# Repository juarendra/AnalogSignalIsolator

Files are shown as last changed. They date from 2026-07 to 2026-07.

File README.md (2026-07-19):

# Analog Signal Isolator

> Isolator sinyal analog 0–5 V untuk menghubungkan sensor ke ESP32, Arduino, MCU, atau PLC tanpa menyatukan ground kedua sisi.

> [!NOTE]
> Panduan pembeli pada halaman ini berlaku untuk PCB yang silkscreen-nya bertuliskan **`AIN`**, **`AOUT`**, `MCU SIDE`, `SENSOR SIDE`, dan `FIT ONE ONLY`.

> [!TIP]
> Produk dikirim sebagai **satu PCB yang sudah dirakit**. Mode bawaan untuk ESP32, yaitu `M2.4V1`, sudah terpasang. Paket tidak mencakup sensor, kabel, catu daya, maupun board ESP32.

<p align="center">
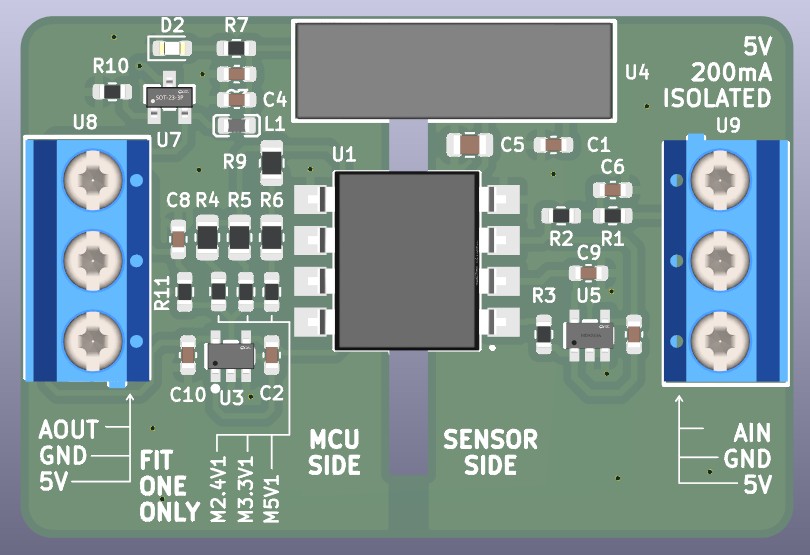
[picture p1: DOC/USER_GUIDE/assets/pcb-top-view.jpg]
PCB Analog Signal Isolator — tampak atas
  
</p>

<p align="center">
  <a href="DOC/USER_GUIDE/start-here.html"><strong>Mulai pemasangan PCB AIN/AOUT &rarr;</strong></a>
  &nbsp;·&nbsp;
  <a href="DOC/USER_GUIDE/assets/pinout-pcb-infographic.png"><strong>Unduh gambar pinout &rarr;</strong></a>
</p>

## Produk ini untuk apa?

Analog Signal Isolator adalah **jembatan aman untuk sinyal analog 0–5 V**. Modul ini menerima tegangan dari sensor di satu sisi, lalu mengirimkan kembali nilai yang sama secara analog ke ADC mikrokontroler/PLC di sisi lain—tanpa hubungan listrik langsung antara kedua ground.

Masalah yang diselesaikan modul ini adalah *ground loop*, noise, dan gangguan ketika sensor berada di mesin/panel yang berbeda dengan ESP32, Arduino, PLC, data logger, atau komputer yang terhubung USB. Sensor tetap memperoleh catu 5 V dari sisi terisolasi, sedangkan MCU membaca sinyal melalui `AOUT`.

```text
Sensor 0–5 V       Isolator analog optik              Mikrokontroler / PLC

AIN ─────────────▶ [ SENSOR SIDE  ║  MCU SIDE ] ─────────────▶ AOUT → ADC
GND sensor         ground terpisah / tidak tersambung          GND MCU
```

**Intinya:** jika sensor menunjukkan 2,50 V pada `AIN`, modul meneruskan nilai proporsional pada `AOUT` sesuai mode yang dipilih. Perangkat lunak kemudian mengubah pembacaan ADC tersebut kembali menjadi nilai sensor melalui kalibrasi dua titik.

## Contoh aplikasi

| Aplikasi | Cara modul digunakan | Manfaat |
| --- | --- | --- |
| **Data logger ESP32** | Sensor tekanan, level, atau posisi 0–5 V dipasang di sisi sensor; `AOUT` dibaca ESP32 pada sisi MCU. | Mengurangi noise dan risiko gangguan ground saat ESP32 memakai USB/Wi-Fi. |
| **Monitoring panel mesin** | Sensor analog pada panel mesin dihubungkan ke `AIN`; sistem monitoring terpisah membaca `AOUT`. | Ground sistem monitoring tidak perlu disatukan dengan ground panel. |
| **Input analog PLC** | Sinyal sensor 0–5 V diteruskan ke input analog PLC melalui sisi MCU. | Membantu pemisahan domain sensor dan kontrol. |
| **Gateway IoT retrofit** | Tambahkan ESP32/Arduino untuk membaca keluaran sensor pada alat lama tanpa mengubah wiring sensor utama. | Integrasi monitoring jarak jauh lebih aman dan rapi. |

> Modul ini bekerja untuk **tegangan analog DC 0–5 V yang sudah dikondisikan**. Untuk sensor 4–20 mA, RTD, thermocouple, AC, atau tegangan PLN, gunakan rangkaian pengondisi sinyal yang tepat terlebih dahulu.

## Kenapa menggunakan modul ini?

- **Isolasi galvanik** antara sisi sensor dan sisi MCU/PLC untuk membantu mengurangi *ground loop* dan gangguan.
- **Input sensor 0–5 V DC** dengan keluaran analog terisolasi `AOUT`.
- **Catu sensor 5 V terisolasi** tersedia langsung pada konektor sisi sensor, hingga **150 mA kontinu** untuk beban sensor.
- **Mode ESP32 2,4 V** sudah dipilih dari pabrik (`M2.4V1`); pilihan lain hanya untuk perubahan konfigurasi terkontrol.
- **Siap untuk dokumentasi dan produksi:** proyek KiCad, Gerber, BOM, skematik, serta prosedur pengujian tersedia di repositori.

## Gambaran koneksi

| MCU SIDE | SENSOR SIDE |
| --- | --- |
| `5V` — catu masuk modul | `5V` — catu keluar terisolasi untuk sensor (maks. 150 mA kontinu) |
| `GND` — ground MCU/PLC | `GND` — ground sensor terisolasi |
| `AOUT` — ke input ADC | `AIN` — dari output sensor 0–5 V |

> [!CAUTION]
> **Jangan hubungkan ground MCU ke ground sensor.** Kedua sisi harus tetap terpisah agar isolasi bekerja.

## Mulai cepat

1. Buka [Mulai di Sini — PCB AIN/AOUT](DOC/USER_GUIDE/start-here.html).
2. Pastikan `M2.4V1` masih terpasang sebagai mode bawaan ESP32. Jangan mengubah jumper mode kecuali Anda memang mengganti jenis host.
3. Hubungkan sensor 0–5 V ke `AIN` dan `GND` pada **SENSOR SIDE**.
4. Hubungkan ADC ke `AOUT`, catu +5 V ke `5V`, dan ground host ke `GND` pada **MCU SIDE**.
5. Nyalakan catu 5 V yang teratur dan memiliki pembatas arus, kemudian kalibrasikan pembacaan 0 V dan 5 V.

## Batas catu untuk sensor

Konektor `5V` pada **SENSOR SIDE** adalah keluaran dari DC/DC isolasi, bukan catu 5 V berdaya besar.

- Gunakan beban sensor total **maksimum 150 mA secara kontinu** (gabungan arus sensor dan aksesori yang mengambil daya dari konektor ini).
- Rating modul DC/DC yang dipasang adalah 5 V / 200 mA, tetapi sebagian arus dipakai oleh rangkaian isolator dan perlu margin untuk suhu serta lonjakan awal. Karena itu **200 mA bukan batas beban sensor eksternal**.
- Bila sensor memiliki arus *inrush*, relay, pemanas, atau motor, gunakan catu sensor terisolasi eksternal yang sesuai. Jangan mengambil daya beban tersebut dari PCB ini.

## Proteksi sistem yang direkomendasikan

Diagram proteksi catu eksternal

PCB ini tidak memasang TVS atau PPTC. Untuk instalasi panel/mesin, pasang proteksi **di luar PCB** pada sisi yang tepat:

1. Gunakan catu **5 V DC teratur**; jangan hubungkan sumber dengan tegangan lebih dari 5 V ke `5V` pada MCU SIDE.
2. Pada kabel `+5V` menuju MCU SIDE, pasang **sekering atau PPTC**. Tentukan nilai *hold/trip* dari arus sistem dan uji arus awal; sebagai titik awal desain, rentang 250–500 mA lazim untuk jalur modul ini, bukan nilai yang otomatis cocok untuk semua sistem.
3. Pasang **TVS unidirectional dengan tegangan kerja 5 V** antara `+5V` dan `GND` **setelah** sekering/PPTC. Pilih energi impuls dan tegangan jepit berdasarkan lingkungan serta kemampuan catu; TVS bukan pengganti sekering.
4. Untuk kabel sensor panjang atau berada di lingkungan berisiko gangguan, TVS 5 V tambahan boleh dipasang dekat konektor **SENSOR SIDE**, dari `5V` ke `GND` sensor saja. Gunakan pelindung sinyal yang dirancang untuk jenis sensor pada jalur `AIN`; jangan memasang komponen sembarang yang mengubah akurasi sinyal.
5. Bila ada shield kabel, terminasi ke chassis/earth di titik masuk panel sesuai praktik sistem. Jangan memakai shield atau perangkat ukur untuk menyatukan `GND` sensor dan `GND` MCU.

> [!WARNING]
> Jangan memasang TVS, jumper, kabel, atau ground melintasi celah/penghalang isolasi. Untuk petir atau surge energi tinggi, gunakan SPD pada pintu masuk sistem dan catu yang sesuai. PCB ini bukan penangkal petir maupun perangkat bersertifikasi keselamatan.

## Dokumentasi

| Dokumen | Kegunaan |
| --- | --- |
| [Mulai di Sini — PCB AIN/AOUT](DOC/USER_GUIDE/start-here.html) | Panduan utama pembeli: jumper, wiring ESP32, uji pertama, dan troubleshooting. |
| [Pinout visual](DOC/USER_GUIDE/pinout-pcb.html) | Cara pemasangan dari foto PCB atas/bawah; buka di browser. |
| [Gambar pinout siap dibagikan](DOC/USER_GUIDE/assets/pinout-pcb-infographic.png) | Infografik untuk pembeli, marketplace, atau teknisi lapangan. |
| [Panduan pengguna](DOC/USER_GUIDE/panduan-visual.html) | Penjelasan kerja, mode, wiring, kalibrasi, dan troubleshooting. |
| [Indeks dokumen teknis](DOC/README.md) | Skematik, BOM, aturan PCB, dan prosedur pengujian. |

## Struktur proyek

| Folder | Isi |
| --- | --- |
| `DOC/USER_GUIDE/` | Panduan pembeli, pinout, gambar produk, dan aset visual. |
| `DOC/` | Skematik, BOM, pengujian, serta referensi teknis Rev B2. |
| `PCB/AnalogIsolator/AnalogIsolator/` | Proyek KiCad, library lokal, Gerber, dan drill file produksi. |

> Rev B2 tidak memasang TVS dan sekering resettable (PPTC) pada papan. Untuk pemasangan yang andal, gunakan catu host 5 V yang teratur, dibatasi arus, dan perlindungan surge pada level sistem bila diperlukan.

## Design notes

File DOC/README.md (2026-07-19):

# Dokumentasi Analog Signal Isolator

Folder ini dipisahkan berdasarkan tujuan agar file yang dibutuhkan pengguna, teknisi, dan produksi tidak tercampur.

| Lokasi | Isi |
| --- | --- |
| [`USER_GUIDE/`](USER_GUIDE/) | Panduan pembeli/pengguna, halaman visual, foto PCB, dan pinout. |
| `00`–`05` | Diagram blok, skematik, pemilihan mode, dan pengkabelan Rev B2. |
| `06_BOM_and_Calculations_RevB2_LCSC.xlsx` | BOM, nilai komponen, dan perhitungan desain. |
| [`09_BOM_Latest_Schematic_LCSC_Mouser.xlsx`](09_BOM_Latest_Schematic_LCSC_Mouser.xlsx) | BOM baru hasil cocokkan dengan skematik saat ini; mencantumkan sumber LCSC dan Mouser serta item yang perlu disetujui. Lihat [catatan validasi](09_BOM_Latest_Schematic_LCSC_Mouser.md). |
| `07`–`08` | Aturan layout PCB serta pengujian/kalibrasi. |

Mulai dari [`USER_GUIDE/start-here.html`](USER_GUIDE/start-here.html) untuk pemasangan PCB fisik yang bertuliskan `AIN/AOUT`. Versi Markdown: [`USER_GUIDE/START_HERE_ID.md`](USER_GUIDE/START_HERE_ID.md). Referensi Rev B2 lama tetap tersedia untuk teknisi.

## Catatan revisi

Foto PCB yang tersedia memperlihatkan pemilih mode berupa jumper solder `M2.4V1`, `M3.3V1`, dan `M5V1`. Dokumen teknik Rev B2 yang lebih lama menyebut `SW1` serta target 2,4/3,0/4,5 V. Selalu ikuti silkscreen dan BOM pada PCB yang benar-benar diterima, lalu lakukan kalibrasi dua titik.

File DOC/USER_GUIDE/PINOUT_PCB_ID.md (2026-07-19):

# Pinout PCB — Analog Signal Isolator

Dokumen ini adalah rujukan pemasangan untuk PCB yang ditunjukkan pada foto di bawah. Gunakan tulisan silkscreen pada PCB sebagai rujukan terakhir apabila orientasi foto atau terminal berbeda.

Untuk pemasangan pertama PCB bertuliskan `AIN/AOUT`, mulai dari [Mulai di Sini](START_HERE_ID.md). Dokumen ini adalah referensi pinout pelengkap.

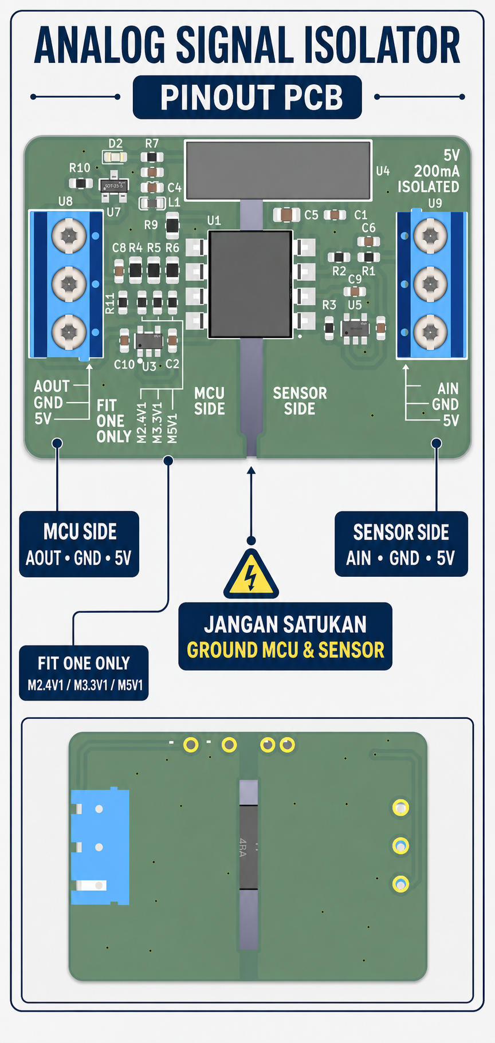
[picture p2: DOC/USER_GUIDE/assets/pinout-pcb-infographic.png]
Infografik pinout PCB


PCB tampak atas

## Konektor

| Sisi PCB | Label silkscreen | Fungsi | Sambungkan ke |
| --- | --- | --- | --- |
| **MCU SIDE** | `AOUT` | Keluaran analog terisolasi | Pin ADC / input analog pada mikrokontroler atau PLC |
| **MCU SIDE** | `GND` | Ground host | Ground mikrokontroler/PLC |
| **MCU SIDE** | `5V` | Catu masuk modul | +5 V DC yang teratur dan dibatasi arus |
| **SENSOR SIDE** | `AIN` | Masukan sinyal analog | Output sensor 0–5 V DC |
| **SENSOR SIDE** | `GND` | Ground sensor terisolasi | Ground sensor saja |
| **SENSOR SIDE** | `5V` | Catu keluar terisolasi untuk sensor | VCC sensor 5 V, maks. 150 mA kontinu |

> [!CAUTION]
> Jangan menghubungkan `GND` pada sisi MCU ke `GND` pada sisi SENSOR. Sambungan tersebut menghilangkan isolasi galvanik.

## Urutan sambungan yang aman

1. Matikan catu daya.
2. Hubungkan `5V`, `GND`, dan `AOUT` pada **MCU SIDE**.
3. Hubungkan `5V`, `GND`, dan `AIN` pada **SENSOR SIDE**.
4. Periksa kembali bahwa output sensor adalah 0–5 V DC terhadap ground sensor.
5. Pastikan tidak ada kabel atau perangkat lain yang menyatukan kedua ground.
6. Pastikan mode bawaan `M2.4V1` masih terpasang untuk ESP32, kemudian nyalakan catu +5 V host.

## Pemilih mode pada PCB ini

Area pemilih mode pada PCB

PCB pada foto menggunakan tiga footprint jumper solder/0 Ω bertuliskan `M2.4V1`, `M3.3V1`, dan `M5V1` dengan instruksi **FIT ONE ONLY**. Produk standar dikirim sebagai PCB rakitan dengan `M2.4V1` sudah terpasang untuk ESP32.

- Biarkan `M2.4V1` terpasang untuk ESP32.
- Bila konfigurasi diubah, pasang/jumper **satu saja** dari ketiga pilihan tersebut saat daya mati.
- `M3.3V1` ditujukan untuk kelas ADC 3,3 V.
- `M5V1` ditujukan untuk kelas ADC 5 V/PLC.
- Jangan menjumper dua atau tiga mode secara bersamaan.

Nama `M3.3V1` dan `M5V1` pada silkscreen menunjukkan kelas ADC, bukan jaminan tepat 3,3 V atau 5,0 V di `AOUT`. Paket teknis Rev B2 menargetkan 2,4 V / 3,0 V / 4,5 V secara nominal. Ukur dan kalibrasikan `AOUT` pada input 0 V dan 5 V sebelum digunakan untuk pengukuran presisi.

## Tampak bawah

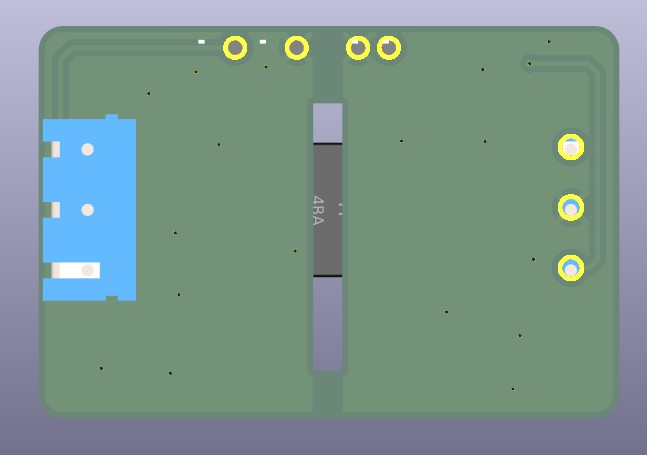
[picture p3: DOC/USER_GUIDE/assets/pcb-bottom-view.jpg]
PCB tampak bawah


Tampak bawah memperlihatkan pemisahan area sisi MCU dan sisi sensor serta celah isolasi. Jangan menambah kabel, jumper, sekrup, atau kontaminasi konduktif yang melintasi celah tersebut.

## Pemeriksaan sebelum operasi

- Sumber `5V` pada sisi MCU harus teratur dan memiliki pembatas arus; Rev B2 tidak memasang TVS dan PPTC di papan.
- Beban pada `5V` sisi sensor tidak boleh lebih dari **150 mA kontinu**. Rating DC/DC 200 mA mencakup konsumsi internal modul, sehingga bukan batas beban sensor eksternal.
- Tegangan sensor harus berada pada 0–5 V DC; tidak ada tegangan negatif.
- Untuk ESP32, mulai dari `M2.4V1` dan gunakan konfigurasi ADC yang tepat.
- Setelah pemasangan, cek `AOUT` pada `AIN = 0 V` dan `AIN = 5 V`, kemudian lakukan kalibrasi dua titik.

Rumus kalibrasi:

```text
VIN = (VMEAS − VZERO) × 5,0 / (VFULL − VZERO)
```

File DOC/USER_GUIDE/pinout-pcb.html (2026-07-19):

# Pinout PCB

Analog Signal Isolator — rujukan pemasangan berdasarkan silkscreen PCB fisik. Mulai pemasangan →

Produk siap ESP32: paket berisi satu PCB yang sudah dirakit dengan M2.4V1 sudah terpasang. Sensor, kabel, catu daya, dan board ESP32 tidak termasuk. Jangan menyatukan ground MCU dan ground sensor; ikuti label silkscreen pada PCB sebagai rujukan akhir.

## Ringkasan pinout siap dibagikan

Infografik pinout PCB Analog Signal Isolator

Versi gambar vertikal untuk dikirim ke pembeli atau dipasang pada halaman produk.

## Tampak atas: konektor dan pemilih mode

Tampak atas PCB Analog Signal Isolator

Sisi kiri adalah MCU SIDE; sisi kanan adalah SENSOR SIDE.

## Arti setiap terminal

Sisi | Label | Fungsi
MCU SIDE | AOUT | Ke input ADC/analog host.
MCU SIDE | GND | Ground host/MCU/PLC.
MCU SIDE | 5V | Masukan catu 5 V untuk modul.
SENSOR SIDE | AIN | Masukan sinyal sensor 0–5 V DC.
SENSOR SIDE | GND | Ground sensor terisolasi.
SENSOR SIDE | 5V | Keluaran +5 V terisolasi untuk sensor, maks. 150 mA kontinu.

## Mode ESP32 sudah dipilih

Area FIT ONE ONLY menggunakan jumper solder/0 Ω. Produk standar dikirim dengan M2.4V1 untuk ESP32 sudah terpasang. Bila konfigurasi diubah saat daya mati, pilih hanya satu: M3.3V1 untuk kelas ADC 3,3 V, atau M5V1 untuk kelas ADC 5 V/PLC. Jangan menjumper lebih dari satu pilihan.

Ukur dan kalibrasikan keluaran AOUT pada AIN = 0 V dan 5 V. Label mode menunjukkan kelas ADC; hasil presisi harus mengikuti pengukuran unit yang digunakan.

## Batas catu sensor

Batasi seluruh beban pada pin 5V SENSOR SIDE hingga 150 mA kontinu. Rating DC/DC 200 mA mencakup konsumsi internal PCB, sehingga tidak seluruhnya tersedia untuk sensor. Gunakan catu terisolasi eksternal untuk relay, motor, pemanas, atau beban dengan lonjakan arus besar.

## Tampak bawah: jaga celah isolasi

Tampak bawah PCB Analog Signal Isolator

Jangan menambahkan kabel, timah, sekrup, atau kontaminasi konduktif melintasi celah isolasi di tengah PCB.

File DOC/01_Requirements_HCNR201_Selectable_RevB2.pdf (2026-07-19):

### 01 Requirements - HCNR201 Rev B2

Rev B2 - Page 1

# 01 - Requirements: HCNR201 Selectable Output Analog Isolator - Rev B2

# Revision summary

Rev B2 adopts a simplified host-power protection chain consisting only of an AO3401A P-channel MOSFET for reverse-polarity protection and an FB1 ferrite bead for conducted-noise filtering. The previous PPTC and input TVS are removed from the production design.

Parameter | Rev B2 requirement
Sensor analog input | 0-5.0 V DC from a conditioned sensor module
Output modes | 0-2.4 V, 0-3.0 V, or 0-4.5 V selected by a mutually exclusive SP3T switch
Host input supply | Regulated 5 V source, preferably with upstream current limiting
Reverse-polarity protection | Q1 AO3401A; drain to 5V_IN, source to protected rail, gate pull-down 100 kΩ
Input surge protection | No on-board TVS in Rev B2
Overcurrent protection | No on-board PPTC in Rev B2
Conducted-noise filtering | FB1 ferrite bead between Q1 and PS1; 0 Ω validation option may share the footprint
Isolated converter | YLPTEC IF0505S-1WR3, regulated isolated 5 V
Analog amplifiers | OPA317 preferred for U1 and U2
Isolation rule | GND_HOST and GND_ISO must remain isolated
Calibration | Fixed precision resistors and two-point software calibration recommended

# Host-supply responsibility

Because Rev B2 omits the PPTC, the upstream USB port, regulator, or system power supply should include appropriate current limiting. Because the input TVS is omitted, the module is intended primarily for short, internal 5 V wiring or installations where surge and ESD protection are provided elsewhere.

# Output-mode requirements

Mode | Host class | Nominal feedback | Nominal output FS
MODE 24 | ESP32-safe / sensitive 3.3 V ADC | 80.6 kΩ | 2.4 V
MODE 33 | Generic 3.3 V ADC | 101 kΩ | 3.0 V
MODE 50 | 5 V ADC / PLC | 150 kΩ + 1.8 kΩ | 4.5 V

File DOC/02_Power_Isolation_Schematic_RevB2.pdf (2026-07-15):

# 02 - POWER AND ISOLATION SCHEMATIC - REV B2

### Only AO3401A reverse-polarity protection and FB1 filtering are fitted

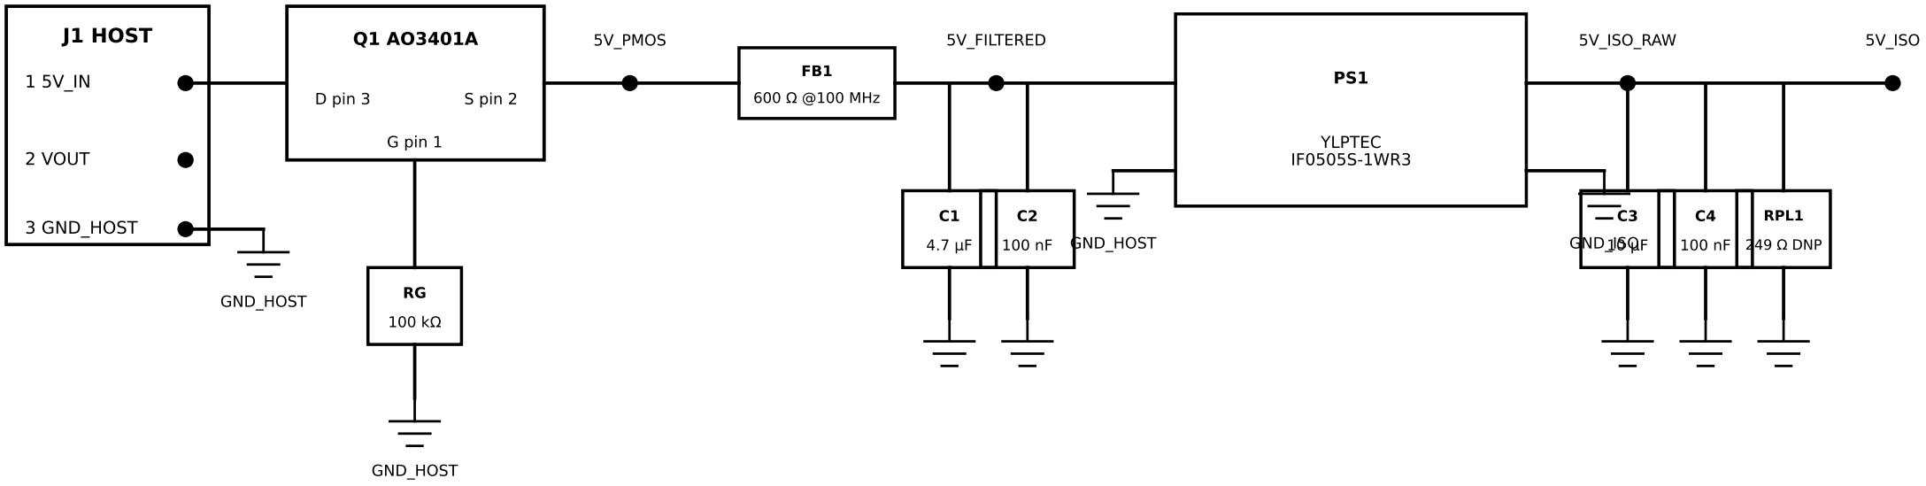
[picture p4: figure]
J1 HOST; 2 VOUT; 3 GND_HOST; D pin 3; S pin 2; G pin 1; 5V_PMOS; GND_HOST; @100 MHz; 5V_FILTERED; YLPTEC IF0505S-1WR3; 5V_ISO_RAW; GND_ISO; RPL1; DNP; 5V_ISO

Design notes

1. Q1 drain (pin 3) connects to 5V_IN; source (pin 2) connects to 5V_PMOS; gate (pin 1) is pulled down by RG = 100 k .
2. FB1 is fitted between Q1 and PS1. Provide a 0 alternative footprint only for validation or cost-down testing.
3. PPTC and input TVS are intentionally omitted in Rev B2. The upstream 5 V source should provide current limiting.
4. RPL1 is DNP when the connected sensor and analog circuit guarantee at least the converter minimum load.
5. GND_HOST and GND_ISO must remain electrically isolated.

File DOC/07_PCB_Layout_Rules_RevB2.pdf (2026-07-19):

### 07 PCB Layout Rules - Rev B2

Rev B2 - Page 1

# 07 - PCB Layout Rules - Rev B2

# Power-input region

Rule | Requirement
Q1 placement | Place AO3401A immediately after J1 5V_IN. Route pin 3 to input, pin 2 to the protected rail, and pin 1 to RG.
Gate pull-down | Place RG = 100 kΩ close to Q1 gate and return it directly to GND_HOST.
FB1 placement | Place FB1 after Q1 and before the DC/DC input capacitors. Keep the noisy side and filtered side copper distinct.
No PPTC / TVS | Do not populate footprints for an on-board PPTC or input TVS in the Rev B2 production layout. The design assumes upstream current limiting and benign 5 V wiring.
DC/DC loop | Place 4.7 µF and 100 nF directly at PS1 input pins. Place 10 µF and 100 nF directly at isolated output pins.
Analog separation | Keep PS1 and FB1 switching/noise region away from SUM1, SUM2, R1B, R24/R33/R50, and the photodiode pins.
Ground domains | Use separate copper for GND_HOST and GND_ISO; no stitching or test jumper between them.
Selector network | Place SW1 and feedback resistors close to U2. Make the three switch positions clearly legible on silkscreen.
Creepage | Maintain barrier creepage/clearance based on the intended working voltage, pollution degree, and enclosure.
Cleanliness | Clean flux around high-impedance photodiode nodes and precision feedback components.

# Release checklist

Verify Q1 source/drain orientation against the exact manufacturer datasheet; confirm FB1 current rating; confirm there is no copper connection across the isolation barrier; and visually verify that the PCB contains no PPTC or input-TVS population in the Rev B2 assembly variant.

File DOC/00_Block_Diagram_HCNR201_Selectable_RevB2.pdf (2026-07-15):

# HCNR201 SELECTABLE OUTPUT ANALOG ISOLATOR - REV B2

### Final input chain: AO3401A reverse-polarity PMOS + ferrite bead; no PPTC and no TVS

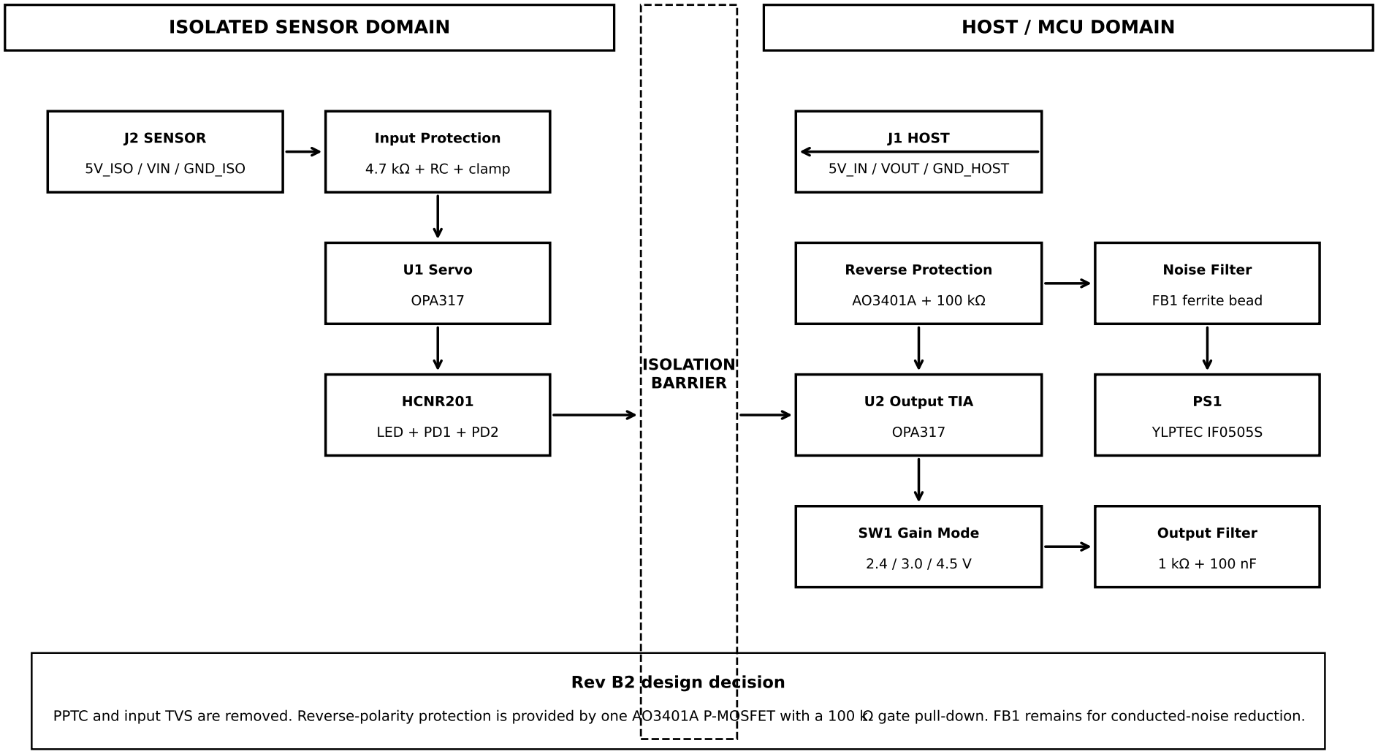
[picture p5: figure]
ISOLATION BARRIER; J2 SENSOR; 5V_ISO / VIN / GND_ISO; Input Protection; 4.7 k + RC + clamp; U1 Servo; OPA317; HCNR201; LED + PD1 + PD2; J1 HOST; 5V_IN / VOUT / GND_HOST; Reverse Protection; Noise Filter; FB1 ferrite bead; YLPTEC IF0505S; U2 Output TIA; SW1 Gain Mode; Output Filter; Rev B2; design decision

ISOLATED SENSOR DOMAIN | HOST / MCU DOMAIN

PPTC and input TVS are removed. Reverse-polarity protection is provided by one AO3401A P-MOSFET with a 100 k gate pull-down. FB1 remains for conducted-noise reduction.

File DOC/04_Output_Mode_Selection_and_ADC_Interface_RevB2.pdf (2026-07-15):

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

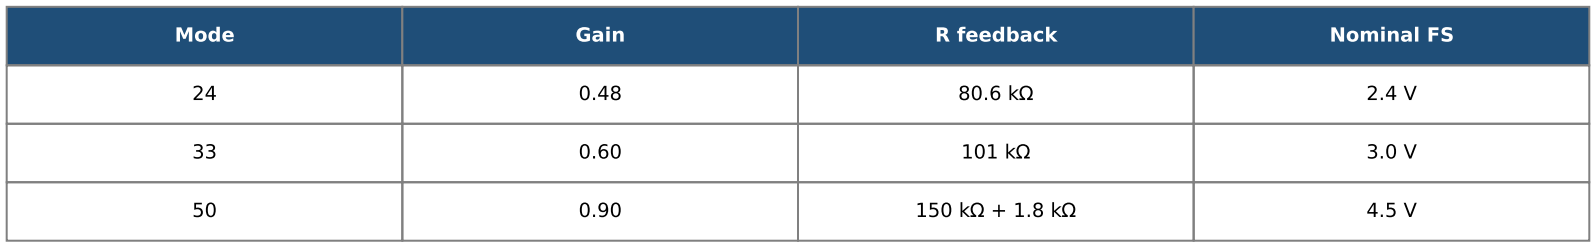
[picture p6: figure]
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

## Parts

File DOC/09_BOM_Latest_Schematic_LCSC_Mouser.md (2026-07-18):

# BOM Terbaru — Skematik KiCad Saat Ini

File pembelian: [`09_BOM_Latest_Schematic_LCSC_Mouser.xlsx`](09_BOM_Latest_Schematic_LCSC_Mouser.xlsx). Versi teks untuk impor ke sistem pembelian: [`09_BOM_Latest_Schematic_LCSC_Mouser.csv`](09_BOM_Latest_Schematic_LCSC_Mouser.csv).

## Ruang lingkup dan sumber

- **Sumber desain:** `PCB/AnalogIsolator/AnalogIsolator/AnalogIsolator.kicad_sch` dan footprint dari PCB yang saat ini berada di *working tree*.
- **Tanggal pengecekan katalog:** 18 Juli 2026. Harga dan stok distributor berubah; cek kembali sebelum pemesanan.
- **Distributor:** kolom LCSC berisi nomor part LCSC untuk pembelian langsung. Kolom Mouser berisi nomor Mouser jika telah diverifikasi; jika yang diberikan hanya MPN, gunakan MPN itu untuk pencarian di Mouser dan verifikasi sebelum membeli.

## Hasil pencocokan skematik ↔ BOM

| Item | Hasil |
| --- | --- |
| Komponen pasif dan aktif | 24 baris BOM mencakup seluruh 33 referensi fisik pada PCB: C1–C10, D2, L1, M2.4V1/M3.3V1/M5V1, R1–R7/R9–R11, dan U1/U3/U4/U5/U7/U8/U9. |
| Pemilih mode | Skematik terbaru menggunakan tiga link 0 Ω (`M2.4V1`, `M3.3V1`, `M5V1`), bukan switch `SW1` pada BOM Rev B2 lama. Hanya **satu** link yang boleh dipasang. |
| Op-amp | Skematik terbaru memakai `U3 = OPA317IDBVR-TP` dan `U5 = OPA392DBVR`; BOM Rev B2 lama menyebut dua OPA317 dan tidak dapat dipakai apa adanya. |
| Footprint presisi | `R2` dan `R11` sekarang ber-footprint 0603. Jangan memakai resistor 0805 dari BOM lama tanpa revisi PCB. |

## Tindakan wajib sebelum rilis produksi

1. **D2 belum terdefinisi.** Skematik hanya memberi nilai `LED`; tentukan warna, intensitas, Vf, dan MPN. Jangan membuat PO untuk D2 sebelum data ini disetujui.
2. **U3 perlu keputusan sumber.** LCSC `C41431830` mengarah ke TECH PUBLIC, bukan TI. Untuk part TI resmi gunakan OPA317IDBVR dari Mouser (`595-OPA317IDBVR`) dan lakukan uji stabilitas loop.
3. **U4 dan U8/U9 tidak memiliki exact-match Mouser yang terverifikasi.** Sumber LCSC dapat digunakan; untuk substitusi Mouser, cek ukuran mekanik, pinout, regulasi, ripple, beban minimum, dan rating isolasi.
4. Jalankan ERC/DRC dan uji 0 V/5 V untuk setiap mode sebelum membekukan BOM sebagai revisi produksi.

## Referensi katalog yang diverifikasi

- [HCNR201-500E di LCSC](https://www.lcsc.com/product-detail/Phototransistors_AVAGO-Broadcom-HCNR201-500E_C27465.html) dan [Mouser](https://www.mouser.com/ProductDetail/Broadcom-Avago/HCNR201-500E)
- [OPA392DBVR di LCSC](https://www.lcsc.com/product-detail/Precision-Op-Amps_Texas-Instruments-OPA392DBVR_C3647166.html) dan [Mouser](https://www.mouser.com/ProductDetail/Texas-Instruments/OPA392DBVR)
- [IF0505S-1WR3 di LCSC](https://www.lcsc.com/product-detail/Isolated-Power-Modules_YLPTEC-IF0505S-1WR3_C5369637.html)
- [AO3401A di LCSC](https://www.lcsc.com/product-detail/MOSFETs_UMW-Youtai-Semiconductor-Co-Ltd-AO3401A_C347476.html)
- [BLM18AG601SN1D di LCSC](https://www.lcsc.com/product-detail/Ferrite-Beads_Murata-Electronics_C19330.html) dan [Mouser](https://www.mouser.com/en/ProductDetail/Murata-Electronics/BLM18AG601SN1D)
- [100 nF CL10B104KB8NNNC di LCSC](https://www.lcsc.com/product-detail/Multilayer-Ceramic-Capacitors-MLCC-SMD-SMT_Samsung-Electro-Mechanics-CL10B104KB8NNNC_C1591.html) dan [Mouser](https://www.mouser.com/ProductDetail/Samsung-Electro-Mechanics/CL10B104KB8NNNC)

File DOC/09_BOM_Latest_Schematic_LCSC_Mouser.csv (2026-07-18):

Item | RefDes | Qty | Value / requirement | Footprint | Recommended manufacturer MPN | LCSC part # | Mouser # / sourcing MPN | Status | Notes
1 | U1 | 1 | High-linearity analog optocoupler | Wide SOP-8 2.54 mm | HCNR201-500E | C27465 | 630-HCNR201-500E | Approved | Core analog isolator; use exact MPN.
2 | U3 | 1 | Low-power RRIO precision op amp | SOT-23-5 | OPA317IDBVR | C41431830 (schematic currently says OPA317IDBVR-TP) | 595-OPA317IDBVR | Review required | LCSC C41431830 is listed as TECH PUBLIC rather than TI; validate pinout and loop stability before substituting the official TI part.
3 | U5 | 1 | Precision RRIO low-noise op amp | SOT-23-5 | OPA392DBVR | C3647166 | 595-OPA392DBVR | Approved | Use exact MPN.
4 | U4 | 1 | 5 V in / 5 V 200 mA isolated regulated DC/DC | SIP 19.5 x 6 mm | IF0505S-1WR3 | C5369637 | Exact Mouser listing not verified | Approved LCSC / review Mouser | Do not replace without verifying pinout regulation no-load behavior ripple and isolation rating.
5 | U7 | 1 | P-channel MOSFET 30 V | SOT-23 | AO3401A | C347476 | PJA3401A_R1_00001 (alternative; verify pinout) | Approved LCSC / review Mouser | LCSC component is marked not recommended for new designs; qualify alternate before production.
6 | U8 U9 | 2 | 3-position 5.00 mm through-hole terminal block | TH P=5.00 mm | KF301-5.0-3P | C474882 | 3-position 5.00 mm terminal block (mechanical substitute) | Approved LCSC / review Mouser | Verify terminal orientation body size and pin pitch before substituting.
7 | L1 | 1 | Ferrite bead 600 ohm at 100 MHz 500 mA | 0603 | BLM18AG601SN1D | C19330 | 81-BLM11A601S | Approved | Use exact MPN.
8 | C1 C3 C6 C8 C9 C10 | 6 | 100 nF 50 V X7R 10% | 0603 | CL10B104KB8NNNC | C1591 | 187-CL10B104KB8NNNC | Approved | Place close to the relevant IC or DC/DC pins.
9 | C2 | 1 | 2.2 nF C0G / NP0 50 V | 0603 | GCM1885C1J222JA16J | C17596087 | GCM1885C1J222JA16J | Approved | Compensation capacitor; do not substitute with X7R.
10 | C4 | 1 | 4.7 uF 10 V X5R 10% | 0603 | CL10A475KP8NNNC | C1705 | 187-CL10A475KP8NNNC | Approved | Check effective capacitance at 5 V DC bias.
11 | C5 | 1 | 10 uF 25 V X5R 10% | 0805 | CL21A106KAYNNNE | C15850 | 187-CL21A106KAYNNNE | Approved | Isolated-side bulk capacitor.
12 | C7 | 1 | 1 nF C0G / NP0 50 V | 0603 | CC0603JRNPO9BN102 | C106246 | 603-C0603JRNPO9BN102 | Approved | Compensation capacitor; do not substitute with X7R.
13 | D2 | 1 | Indicator LED; colour and Vf unspecified | 0603 | TBD | TBD | TBD | Blocker | Latest schematic only says LED. Specify colour luminous intensity Vf and polarity before release.
14 | M2.4V1 M3.3V1 M5V1 | 3 | 0 ohm mode-selection links; fit one only | 0603 | RC0603JR-070RL | C21189 | 603-RC0603JR-070RL | Approved | Populate exactly one link according to selected output mode.
15 | R1 | 1 | 4.7 kohm 1% | 0603 | RC0603FR-074K7L | C99782 | 603-RC0603FR-074K7L | Approved | Input series/protection resistor.
16 | R2 | 1 | 164 kohm 0.1% thin film 25 ppm/C or better | 0603 | RT0603BRD07164KL | Source by MPN / verify current LCSC listing | 603-RT0603BRD07164KL | Review required | The previous BOM used 0805; latest PCB footprint is 0603.
17 | R3 | 1 | 220 ohm 1% | 0603 | RC0603FR-07220RL | C107696 | 603-RC0603FR-07220RL | Approved | LED current limiting resistor in analog loop.
18 | R4 | 1 | 80.6 kohm 0.1% thin film | 0805 | PTFR0805B80K6P9 | C2849352 | PTFR0805B80K6P9 | Approved | Mode 2.4 V gain resistor.
19 | R5 | 1 | 101 kohm 0.1% thin film | 0805 | RN73R2ATTD1013B25 | C4150121 | RN73R2ATTD1013B25 | Approved | Mode 3.3 V class gain resistor.
20 | R6 | 1 | 150 kohm 0.1% thin film | 0805 | RT0805BRD07150KL | C136927 | RT0805BRD07150KL | Approved | Mode 5 V class gain resistor.
21 | R7 | 1 | 1 kohm 1% | 0603 | RC0603FR-071KL | C22548 | 603-RC0603FR-071KL | Approved | Output series resistor.
22 | R9 | 1 | 1.8 kohm 0.1% thin film | 0805 | RT0805BRE071K8L | C513603 | RT0805BRE071K8L | Approved | Series gain resistor for the 5 V class mode.
23 | R10 | 1 | 100 kohm 1% | 0603 | RC0603FR-07100KL | C25803 | 603-RC0603FR-07100KL | Approved | PMOS gate pull-down resistor.
24 | R11 | 1 | 1 kohm 0.1% thin film 25 ppm/C or better | 0603 | RT0603BRD071KL | Source by MPN / verify current LCSC listing | 603-RT0603BRD071KL | Review required | The previous BOM used an 0805 resistor; latest PCB footprint is 0603.

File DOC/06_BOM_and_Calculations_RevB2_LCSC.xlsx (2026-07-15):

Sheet: Cover
HCNR201 Selectable Output Analog Isolator BOM and Calculations — Rev B
Document | 06_BOM_and_Calculations_LCSC.xlsx
Revision | Rev B2 - PMOS + ferrite bead only
Input range | 0–5 V conditioned sensor
Output modes | 2.4 V / 3.0 V / 4.5 V
Core parts | HCNR201-500E, OPA388, regulated isolated 5V DC/DC
Calibration | Recommended: fixed resistors + software two-point calibration
Warning | GND_ISO and GND_HOST must never be connected
Preferred op-amp | TI OPA317IDBVR — LCSC C2058367
Preferred isolated DC/DC | YLPTEC IF0505S-1WR3 — LCSC C5369637
Sourcing snapshot | Listings checked 2026-07-15; recheck stock and price before ordering
Power protection | AO3401A P-MOSFET + 100 kΩ gate pull-down
Noise filter | FB1 ferrite bead, 600 Ω @ 100 MHz class
Not fitted | PPTC and input TVS
System assumption | Upstream 5 V source is regulated and current-limited

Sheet: Design Inputs
Parameter | Symbol | Value | Unit | Editable? | Note
Max sensor input | VIN_FS | 5 | V | Yes | Conditioned sensor output
R1 protection | R1A | 4700 | ohm | Yes | Series protection resistor
R1 precision leg | R1B | 164000 | ohm | Yes | Thin-film 0.1% recommended
K3 minimum design corner | K3_MIN | 0.93 | V/V | Yes | Derated corner
K3 nominal | K3_NOM | 1 | V/V | No | Nominal
K3 maximum design corner | K3_MAX | 1.07 | V/V | Yes | Derated corner
R2 mode 24 | R2_24 | 80600 | ohm | Yes | Nominal 2.4 V output
R2 mode 33 | R2_33 | 101000 | ohm | Yes | Nominal 3.0 V output
R2 mode 50 | R2_50 | 151800 | ohm | Yes | Nominal 4.5 V output
Input capacitor | CIN | 1e-07 | F | Yes | 100 nF
Compensation capacitor input | CC1 | 1e-09 | F | Yes | 1 nF C0G
Compensation capacitor output | CC2 | 2.2e-09 | F | Yes | 2.2 nF C0G
Output series resistor | ROUT | 1000 | ohm | Yes | 1 kΩ
Output filter capacitor | COUT | 1e-07 | F | Yes | 100 nF
Preload resistor | RPL1 | 249 | ohm | Yes | Needed for IF0505S minimum load
Isolated converter max current | IDC_MAX | 0.2 | A | No | IF0505S-1WR3
Per-opamp max supply current | IQ_OPA | 3.5e-05 | A | No | OPA317 maximum supply current used for design budget
Reserve current | I_RESERVE | 0.015 | A | Yes | Design margin
Isolated output nominal | VISO | 5.000000 | V | Yes | Nominal regulated isolated rail
Estimated maximum LED current | ILED_MAX | 0.008500 | A | Yes | Conservative HCNR201 LED budget

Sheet: Calculations
Calculation | Formula result | Unit | Mode 24 | Mode 33 | Mode 50
R1 total | 168700 | ohm | 168700 | 168700 | 168700
Gain nominal | 0.4777711915 | V/V | 0.4777711915 | 0.5986959099 | 0.8998221695
VOUT at 5V, K3 nominal | 2.388855957 | V | 2.388855957 | 2.993479549 | 4.499110848
VOUT at 5V, K3 min | 2.22163604 | V | 2.22163604 | 2.783935981 | 4.184173088
VOUT at 5V, K3 max | 2.556075874 | V | 2.556075874 | 3.203023118 | 4.814048607
Input RC cutoff | 338.6275385 | Hz | 338.6275385 | 338.6275385 | 338.6275385
Output comp pole | 897.5577661 | Hz | 897.5577661 | 716.2688708 | 476.5688798
Preload current | 0.02008032129 | A | 0.02008032129 | 0.02008032129 | 0.02008032129
Estimated sensor current budget | 0.1563846787 | A | 0.1563846787 | 0.1563846787 | 0.1563846787
PMOS / filter check | Formula result | Unit | Mode 24 | Mode 33 | Mode 50
Assumed AO3401A RDS(on) | 0.0700 | ohm | 0.0700 | 0.0700 | 0.0700
Assumed host input current | 0.2000 | A | 0.2000 | 0.2000 | 0.2000
Estimated PMOS voltage drop | 0.0140 | V | 0.0140 | 0.0140 | 0.0140

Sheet: Mode Summary
Mode | Target output FS | Nominal gain | Nominal R2 | Typical use
MODE 24 | 2.4 | 0.48 | 80600 | ESP32-safe / sensitive 3.3 V ADC
MODE 33 | 3 | 0.6 | 101000 | Generic 3.3 V MCU ADC
MODE 50 | 4.5 | 0.9 | 151800 | 5 V ADC / Arduino / PLC analog input

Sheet: BOM
Item | RefDes | Qty | Description | Preferred part/value | Status | Note
1 | U3 | 1 | Analog optocoupler | Broadcom HCNR201-500E — C27465 | Required | Core analog isolator
2 | U1,U2 | 2 | Precision RRIO zero-drift op-amp | TI OPA317IDBVR — C2058367 | Required | Preferred cost/performance part
3 | PS1 | 1 | Regulated isolated DC/DC | YLPTEC IF0505S-1WR3 — C5369637 | Required | 5 V to regulated isolated 5 V
4 | SW1 | 1 | 3-position selector | SHOU HAN SK13D07VG5 — C393948 | Required | SP3T mutually exclusive mode selection
5 | RPROT | 1 | Input protection resistor | UNI-ROYAL 0603WAF4701T5E — C23162 | Required | 4.7 kΩ, 1%
6 | R1B | 1 | Precision input resistor | Stackpole RNCF0805BKE164K — C4010785 | Required | 164 kΩ, 0.1% thin-film
7 | RLED | 1 | LED current limit | UNI-ROYAL 0603WAF2200T5E — C22962 | Required | 220 Ω, 1%
8 | R24 | 1 | Mode 24 feedback | RESI PTFR0805B80K6P9 — C2849352 | Required | 80.6 kΩ, 0.1%
9 | R33 | 1 | Mode 33 feedback | KOA RN73R2ATTD1013B25 — C4150121 | Required | 101 kΩ, 0.1%
10 | R50A,R50B | 2 | Mode 50 feedback | 150 kΩ C136927 + 1.8 kΩ C513603 | Required | Series total 151.8 kΩ
11 | CC1 | 1 | Input compensation | YAGEO CC0603JRNPO9BN102 — C106246 | Required | 1 nF NP0/C0G
12 | CC2 | 1 | Output compensation | Murata GCM1885C1J222JA16J — C17596087 | Required | 2.2 nF C0G
13 | CIN,COUT,CDEC | 6 | 100 nF bypass/filter | Samsung CL10B104KB8NNNC — C1591 | Required | 100 nF X7R
14 | ROUT | 1 | Output series resistor | YAGEO RC0603FR-071KL — C22548 | Required | 1 kΩ, 1%
15 | CBULK | 2 | Bulk decoupling | Samsung CL21A106KAYNNNE — C15850 | Required | 10 µF, 25 V
16 | RPL1 | 1 | Preload resistor | UNI-ROYAL 1206W4F2490T5E - C17959 | Conditional | 249 Ω, 0.25 W; DNP if load guaranteed
17 | Q1,RG | 2 | Reverse-polarity protection | UMW AO3401A C347476 + 100 kΩ resistor | Required | Drain to 5V_IN, source to protected rail, gate pull-down
18 | FB1 | 1 | Ferrite bead | Murata BLM18AG601SN1D - C19330 | Required | 600 Ω @100 MHz, 500 mA; 0 Ω only for validation

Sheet: BOM LCSC
Item | RefDes | Qty | Function | Manufacturer | MPN | LCSC Part # | Package | Value / Rating | Fit | Availability note | Alternate | Alternate LCSC | Source URL | Engineering note
1 | U3 | 1 | High-linearity analog optocoupler | Broadcom | HCNR201-500E | C27465 | SOP-8 wide body | K3 ±5% class | Required | Listing verified 2026-07-15 |  |  | https://www.lcsc.com/product-detail/C27465.html | Confirm exact footprint and isolation courtyard.
2 | U1,U2 | 2 | Precision single op-amp | Texas Instruments | OPA317IDBVR | C2058367 | SOT-23-5 | 1.8–5.5 V, RRIO, zero-drift | Required | Listing verified 2026-07-15 | TLV9001IDBVR | C398363 | https://www.lcsc.com/product-detail/C2058367.html | Preferred cost/performance choice; revalidate loop compensation.
3 | PS1 | 1 | Regulated isolated DC/DC | YLPTEC | IF0505S-1WR3 | C5369637 | SIP 19.5×6 mm | 5 V in, 5 V/200 mA out, 3 kVDC test | Required | Listing verified 2026-07-15 |  |  | https://www.lcsc.com/product-detail/C5369637.html | Minimum-load requirement applies.
4 | SW1 | 1 | Output mode selector | SHOU HAN | SK13D07VG5 | C393948 | THT right-angle | SP3T, 3 positions | Required | Listing verified 2026-07-15 |  |  | https://www.lcsc.com/product-detail/C393948.html | Verify common pin and mechanical orientation.
5 | RPROT | 1 | Input protection resistor | UNI-ROYAL | 0603WAF4701T5E | C23162 | 0603 | 4.7 kΩ, 1%, 100 mW | Required | Listing verified; stock may be zero | RC0603FR-074K7L | C99782 | https://www.lcsc.com/product-detail/C23162.html | Generic reputable equivalent acceptable.
6 | R1B | 1 | Precision input gain resistor | Stackpole | RNCF0805BKE164K | C4010785 | 0805 | 164 kΩ, 0.1%, ±25 ppm/°C | Required | Listing verified 2026-07-15 |  |  | https://www.lcsc.com/product-detail/C4010785.html | Thin-film required.
7 | RLED | 1 | LED current limiter | UNI-ROYAL | 0603WAF2200T5E | C22962 | 0603 | 220 Ω, 1%, 100 mW | Required | Listing verified; stock may be zero | RC0603FR-07220RL | C107696 | https://www.lcsc.com/product-detail/C22962.html | Generic reputable equivalent acceptable.
8 | R24 | 1 | MODE 24 feedback | RESI | PTFR0805B80K6P9 | C2849352 | 0805 | 80.6 kΩ, 0.1% thin-film | Required | Listing verified 2026-07-15 |  |  | https://www.lcsc.com/product-detail/C2849352.html | 2.4 V nominal full scale.
9 | R33 | 1 | MODE 33 feedback | KOA Speer | RN73R2ATTD1013B25 | C4150121 | 0805 | 101 kΩ, 0.1%, ±25 ppm/°C | Required | Listing verified 2026-07-15 |  |  | https://www.lcsc.com/product-detail/C4150121.html | 3.0 V nominal full scale.
10 | R50A | 1 | MODE 50 feedback coarse | Yageo | RT0805BRD07150KL | C136927 | 0805 | 150 kΩ, 0.1% thin-film | Required | Listing verified 2026-07-15 |  |  | https://www.lcsc.com/product-detail/C136927.html | Series with R50B.
11 | R50B | 1 | MODE 50 feedback fine | Yageo | RT0805BRE071K8L | C513603 | 0805 | 1.8 kΩ, 0.1% thin-film | Required | Listing verified 2026-07-15 |  |  | https://www.lcsc.com/product-detail/C513603.html | R50 total = 151.8 kΩ.
12 | CC1 | 1 | Input-loop compensation | Yageo | CC0603JRNPO9BN102 | C106246 | 0603 | 1 nF NP0/C0G, 50 V | Required | In-stock listing observed |  |  | https://www.lcsc.com/product-detail/C106246.html | Starting value; tune after step test.
13 | CC2 | 1 | Output-loop compensation | Murata | GCM1885C1J222JA16J | C17596087 | 0603 | 2.2 nF C0G, 63 V | Required | Listing verified; stock may be zero | 0603J0160222JCT | C2282079 | https://www.lcsc.com/product-detail/C17596087.html | Keep alternate C0G footprint option.
14 | CIN,COUT,CDEC1-CDEC4 | 6 | 100 nF filter/decoupling | Samsung Electro-Mechanics | CL10B104KB8NNNC | C1591 | 0603 | 100 nF X7R, 50 V | Required | Listing verified 2026-07-15 |  |  | https://www.lcsc.com/product-detail/C1591.html | Place decouplers close to devices.
15 | CIN_BULK | 1 | DC/DC input bulk | Samsung Electro-Mechanics | CL10A475KP8NNNC | C1705 | 0603 | 4.7 µF X5R, 10 V | Required | In-stock listing observed |  |  | https://www.lcsc.com/product-detail/C1705.html | Check effective capacitance at 5 V bias.
16 | CISO_BULK | 1 | DC/DC output bulk | Samsung Electro-Mechanics | CL21A106KAYNNNE | C15850 | 0805 | 10 µF X5R, 25 V | Required | Listing verified; stock may be zero |  |  | https://www.lcsc.com/product-detail/C15850.html | Use equivalent after DC-bias validation.
17 | ROUT | 1 | Output series resistor | Yageo | RC0603FR-071KL | C22548 | 0603 | 1 kΩ, 1%, 100 mW | Required | Listing verified; stock may be zero |  |  | https://www.lcsc.com/product-detail/C22548.html | Host-specific clamps remain on host board.
18 | RPL1 | 1 | Isolated supply preload | UNI-ROYAL | 1206W4F2490T5E | C17959 | 1206 | 249 Ω, 1%, 0.25 W | DNP/Conditional | Listing verified 2026-07-15 |  |  | https://www.lcsc.com/product-detail/C17959.html | Fit only if minimum load is not guaranteed.
19 | DCL1,DCL2 | 2 | Low-leakage clamps | Nexperia | BAV199,215 | C40919 | SOT-23 | Dual low-leakage diode | Recommended | Listing verified 2026-07-15 | BAV199 | C7461107 | https://www.lcsc.com/product-detail/C40919.html | Validate leakage across temperature.
20 | DLED | 1 | LED reverse protection | ST(Semtech) | 1N4148WS | C57759 | SOD-323 | Fast switching diode | Recommended | Listing verified 2026-07-15 | 1N4148WS-7-F | C60580 | https://www.lcsc.com/product-detail/C57759.html | Install anti-parallel to HCNR LED.
21 | RG | 1 | PMOS gate pull-down resistor | UNI-ROYAL | 0603WAF1003T5E | C25803 | 0603 | 100 kΩ, 1%, 100 mW | Required | Standard stocked value; recheck before ordering |  |  | https://www.lcsc.com/product-detail/C25803.html | Connect AO3401A gate to GND_HOST. Place close to Q1.
22 | Q1 | 1 | Reverse-polarity P-channel MOSFET | UMW | AO3401A | C347476 | SOT-23 | P-channel MOSFET | Required | Listing verified 2026-07-15 |  |  | https://www.lcsc.com/product-detail/C347476.html | Pin 3 drain -> 5V_IN; pin 2 source -> protected rail; pin 1 gate -> RG.
23 | - | 0 | Input TVS | - | - | - | - | Not fitted in Rev B2 | Removed Rev B2 | No on-board TVS; system-level protection may be added externally |  |  |  | PPTC and TVS are intentionally omitted from the Rev B2 production design.
24 | FB1 | 1 | Host-rail ferrite bead | Murata | BLM18AG601SN1D | C19330 | 0603 | 600 Ω @ 100 MHz, 500 mA | Required | Listing verified 2026-07-15 | 0 Ω validation link |  | https://www.lcsc.com/product-detail/C19330.html | Place after Q1 and before PS1 input capacitors. Use 0 Ω only for validation.
25 | J1,J2 | 2 | 3-position terminal block | Cixi Kefa | KF301-5.0-3P | C474882 | THT 5.0 mm | 3 positions | Required | Listing verified 2026-07-15 |  |  | https://www.lcsc.com/product-detail/C474882.html | Clear silkscreen and polarity labeling required.

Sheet: Sourcing Notes
Topic | Decision / requirement
Preferred op-amp | OPA317IDBVR (C2058367). TLV9001IDBVR (C398363) is a cost-down alternate requiring full validation.
Isolated converter | YLPTEC IF0505S-1WR3 (C5369637), regulated 5 V. Keep RPL1 as DNP option.
MODE 50 | Implemented as 150 kΩ + 1.8 kΩ series because 151.8 kΩ precision parts are less common.
Stock warning | Stock and price are dynamic; this is a part-identification snapshot, not a purchasing guarantee.
Footprints | Check manufacturer mechanical drawings before PCB release, especially U3, PS1, SW1, Q1, D1 and J1/J2.
Qualification | Validate YLPTEC and Asian-brand protection parts by incoming inspection and batch testing.
Calibration | Fixed resistors plus two-point software calibration remain the recommended production method.
Rev B2 protection chain | 5V_IN -> AO3401A -> FB1 -> IF0505S. RG = 100 kΩ pulls the gate to GND_HOST.
Removed components | The on-board PPTC and input TVS are not fitted in Rev B2.
Power-source assumption | Use a regulated 5 V source with upstream current limiting. Rev B2 is intended for short/internal supply wiring or system-level surge protection.
FB1 assembly | FB1 is fitted in production. A 0 Ω alternative is allowed only during validation and noise comparison.

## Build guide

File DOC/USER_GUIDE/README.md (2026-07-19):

# Referensi Teknik Rev B2 — Analog Signal Isolator

**Versi desain: Rev B2**
Modul ini mengirimkan tegangan analog DC dari sisi sensor ke sisi mikrokontroler/PLC **tanpa menyatukan ground kedua sisi**. Modul menerima sinyal sensor yang sudah dikondisikan pada rentang **0–5 V DC** dan menghasilkan tegangan keluaran yang dapat dipilih hingga **2,4 V, 3,0 V, atau 4,5 V**.

> [!WARNING]
> Ini adalah referensi teknik Rev B2, bukan panduan utama pembeli untuk PCB pada foto. Referensi ini memakai istilah `J1/J2`, `VIN/VOUT`, dan `SW1`; PCB fisik memakai `AIN/AOUT` dan jumper solder. Untuk pemasangan PCB fisik, gunakan [Mulai di Sini — PCB AIN/AOUT](START_HERE_ID.md).

> [!IMPORTANT]
> Ini adalah modul isolator sinyal bertegangan rendah untuk sistem elektronik. Isolasi pada modul **bukan** pernyataan sertifikasi keselamatan, bukan pengganti proteksi petir/surge, dan tidak untuk langsung mengukur tegangan listrik PLN.

Infografik pinout PCB

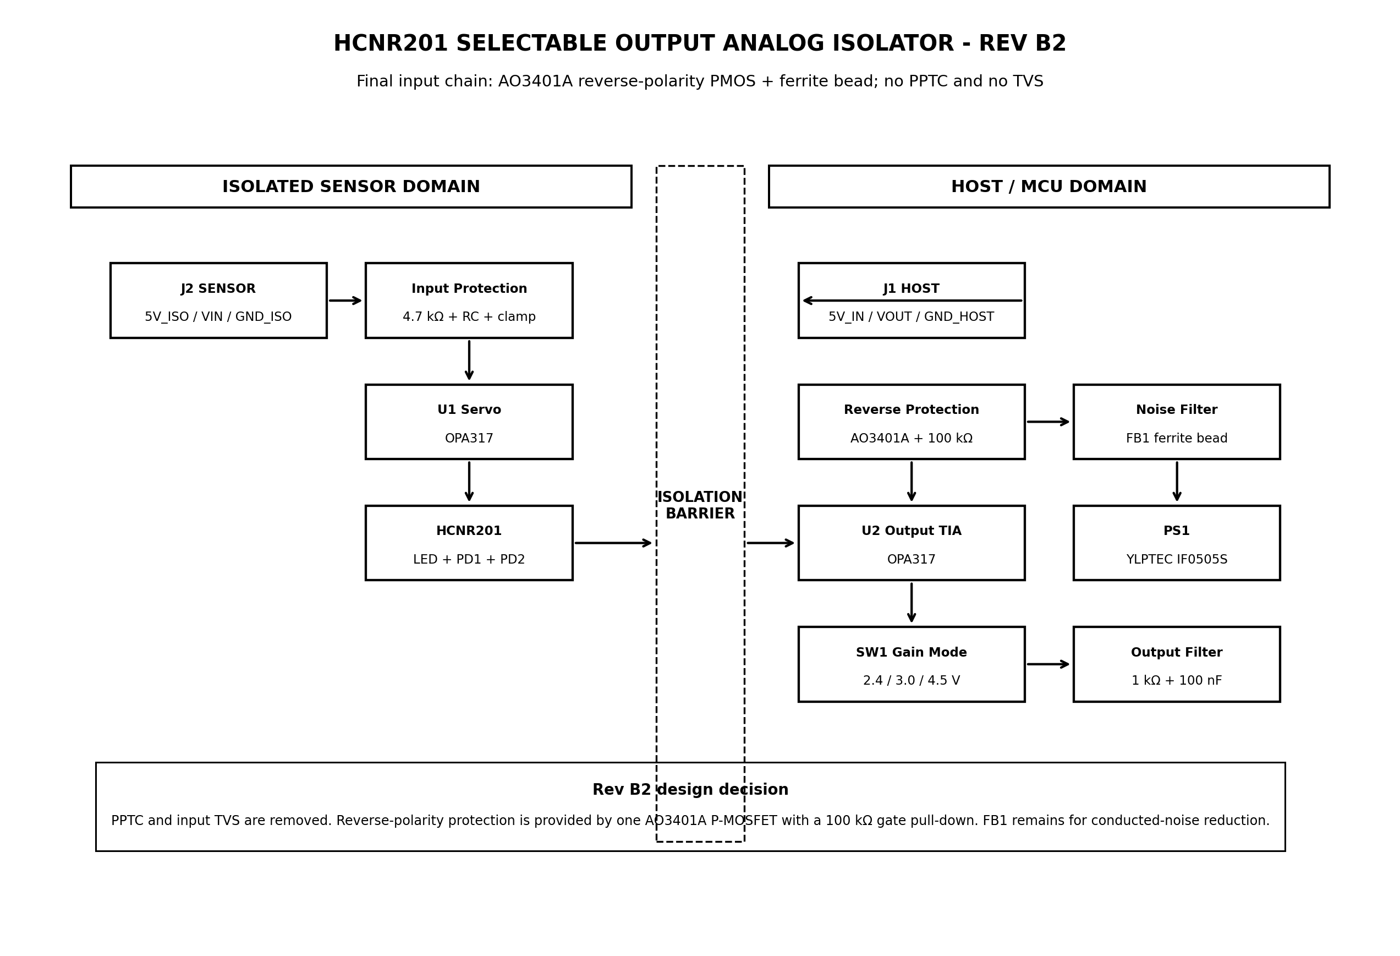
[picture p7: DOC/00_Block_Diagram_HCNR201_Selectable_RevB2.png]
Alur kerja modul


## Cocok untuk apa?

- Menghubungkan sensor analog 0–5 V ke ESP32, Arduino, MCU 3,3 V, ADC, atau PLC.
- Menghilangkan masalah *ground loop* dan gangguan antara sisi sensor dengan sisi kontrol.
- Memberi catu 5 V yang terisolasi kepada sensor melalui konektor sensor.

**Bukan untuk:** sinyal sensor mentah 4–20 mA, sensor dengan keluaran melebihi 5 V, sinyal AC, atau input yang ground-nya harus tersambung ke ground MCU. Gunakan rangkaian pengondisi sinyal yang sesuai terlebih dahulu.

## Spesifikasi ringkas

| Parameter | Nilai / keterangan |
| --- | --- |
| Input sinyal | 0–5,0 V DC dari sensor yang telah dikondisikan |
| Catu host | 5 V DC teratur (*regulated*), sebaiknya memiliki pembatas arus |
| Keluaran | 0–2,4 V / 0–3,0 V / 0–4,5 V nominal, dipilih dengan SW1 |
| Isolasi catu sensor | DC/DC 5 V ke 5 V terisolasi (IF0505S-1WR3) |
| Filter keluaran | 1 kΩ seri + 100 nF; tidak ditujukan untuk sinyal cepat |
| Rentang frekuensi praktis | Input mulai teredam sekitar 339 Hz; gunakan untuk sinyal DC/lambat |
| Proteksi polaritas catu | Ada, melalui MOSFET Q1 |
| Proteksi surge / sekering internal | **Tidak ada** pada Rev B2 (TVS dan PPTC tidak dipasang) |

## Kenali sisi konektor

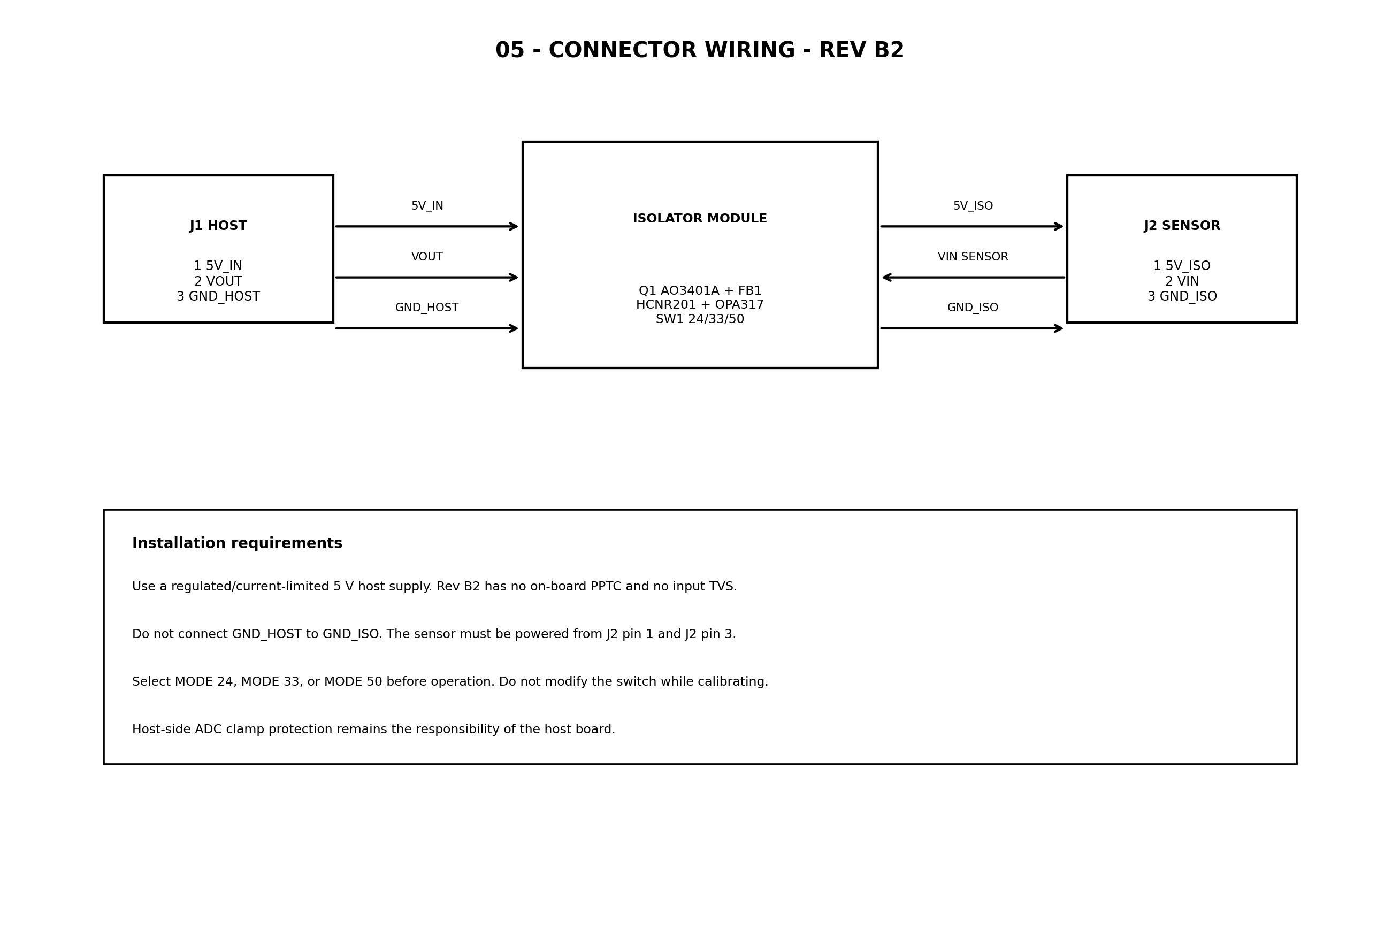
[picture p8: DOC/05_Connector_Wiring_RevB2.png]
Diagram pengkabelan


| Konektor | Pin | Nama | Sambungkan ke |
| --- | ---: | --- | --- |
| **J1 — HOST** | 1 | `5V_IN` | Catu host +5 V |
|  | 2 | `VOUT` | Pin ADC / input analog host |
|  | 3 | `GND_HOST` | Ground host/MCU/PLC |
| **J2 — SENSOR** | 1 | `5V_ISO` | Catu +5 V untuk sensor (keluaran terisolasi modul) |
|  | 2 | `VIN` | Keluaran analog sensor 0–5 V |
|  | 3 | `GND_ISO` | Ground sensor |

> [!CAUTION]
> **Jangan pernah menyambungkan `GND_HOST` ke `GND_ISO`.** Kedua ground tersebut harus tetap terpisah agar fungsi isolasi bekerja. Jangan pula memberi catu 5 V eksternal ke `5V_ISO` kecuali Anda memang memahami arsitektur catu terisolasinya.

## Memilih mode keluaran

Pilih mode **saat daya mati**, sesuai batas tegangan ADC yang digunakan. Hanya satu mode yang boleh aktif.

| Mode | Keluaran pada input 5 V (nominal) | Rekomendasi pemakaian |
| --- | ---: | --- |
| **MODE 24** | 2,4 V | ESP32 atau ADC 3,3 V yang membutuhkan margin aman |
| **MODE 33** | 3,0 V | ADC MCU 3,3 V umum |
| **MODE 50** | 4,5 V | ADC 5 V, Arduino 5 V, atau input analog PLC |

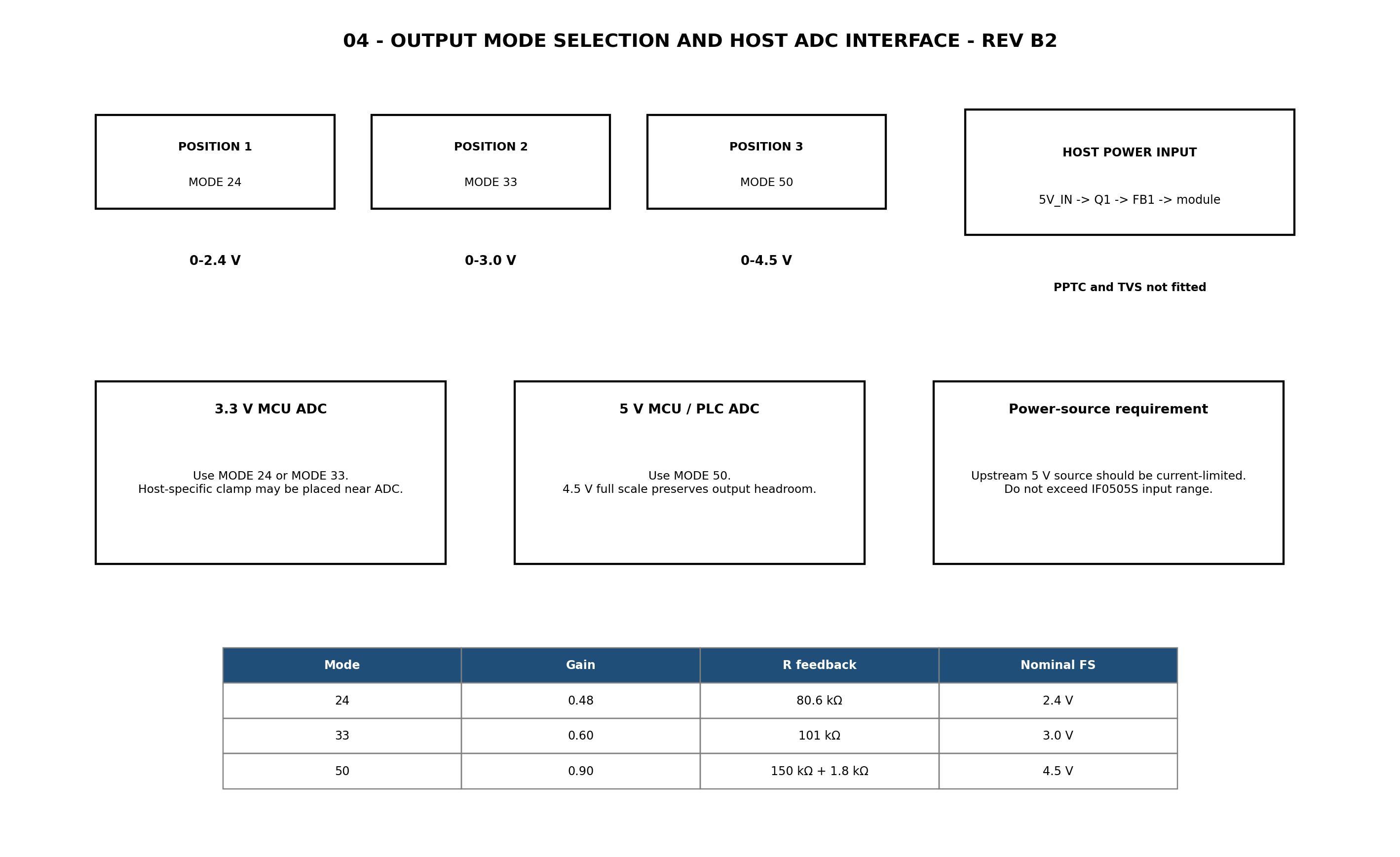
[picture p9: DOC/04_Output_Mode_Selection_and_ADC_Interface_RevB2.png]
Pilihan mode dan antarmuka ADC


Untuk ESP32, gunakan **MODE 24** sebagai pilihan awal. Pastikan juga konfigurasi attenuasi dan kalibrasi ADC ESP32 sesuai; ketelitian ADC internal dapat berbeda antar papan.

## Pemasangan cepat

1. Matikan seluruh catu daya dan pilih mode keluaran yang sesuai.
2. Pastikan sensor benar-benar memiliki output **0–5 V DC** dan tidak akan mengeluarkan tegangan negatif atau lebih dari 5 V.
3. Hubungkan J1: `5V_IN` ke +5 V host, `GND_HOST` ke ground host, dan `VOUT` ke ADC host.
4. Hubungkan J2: beri sensor daya dari `5V_ISO` dan `GND_ISO`, lalu hubungkan output sensor ke `VIN`.
5. Periksa kembali bahwa tidak ada kabel antara `GND_HOST` dan `GND_ISO`.
6. Nyalakan catu host 5 V yang teratur dan dibatasi arus. Untuk pengujian pertama, gunakan limit arus yang rendah namun cukup untuk sensor dan modul.
7. Berikan input sensor 0 V, lalu 5 V. Tegangan `VOUT` seharusnya mendekati 0 V dan nilai skala penuh mode yang dipilih.
8. Lakukan kalibrasi perangkat lunak sebelum memakai hasil pengukuran sebagai nilai presisi.

## Kalibrasi dua titik

Nilai keluaran nominal bisa sedikit berbeda akibat toleransi optocoupler, sensor, dan ADC. Kalibrasi dua titik menghilangkan sebagian besar kesalahan tersebut.

1. Terapkan `VIN = 0,000 V`; baca dan simpan sebagai `VZERO`.
2. Terapkan `VIN = 5,000 V`; baca dan simpan sebagai `VFULL`.
3. Untuk setiap pembacaan `VMEAS`, hitung tegangan input sensor:

```text
VIN = (VMEAS − VZERO) × 5,0 / (VFULL − VZERO)
```

Simpan pasangan kalibrasi untuk setiap unit dan setiap mode yang digunakan. Kalibrasi ini adalah kalibrasi **jalur isolator**; bila sensor perlu kalibrasi fisik (misalnya suhu atau tekanan), lakukan secara terpisah.

Contoh: jika MODE 24 menghasilkan `VZERO = 0,012 V`, `VFULL = 2,390 V`, dan ADC membaca `1,201 V`, maka `VIN` kira-kira `2,50 V`.

## Hal yang penting untuk keandalan

- Gunakan kabel catu 5 V yang pendek atau tambahkan proteksi surge/ESD pada level sistem bila kabel panjang/lingkungan bising.
- Rev B2 tidak memiliki TVS dan sekering resettable (PPTC) di papan. Sumber 5 V hulu harus memiliki pembatas arus yang memadai.
- Perlindungan clamp pada pin ADC merupakan tanggung jawab papan host. Jangan mengandalkan resistor 1 kΩ keluaran sebagai satu-satunya proteksi.
- Jangan mengubah pemilih mode saat proses kalibrasi atau ketika sistem sedang mengambil data penting.
- Jika sensor tidak stabil setelah dipasang, periksa kebutuhan beban minimum konverter DC/DC dan kualitas kabel/catu sensor.

## Pemeriksaan dan pemecahan masalah

| Gejala | Periksa terlebih dahulu |
| --- | --- |
| `VOUT` selalu 0 V | Catu +5 V di J1, orientasi/terminal J1, sensor mendapat 5 V di J2, dan `VIN` benar-benar memiliki tegangan terhadap `GND_ISO`. |
| Keluaran terlalu tinggi untuk ADC | Mode SW1 salah; pilih MODE 24/33 untuk ADC 3,3 V. Pastikan ADC dan clamp host tidak rusak. |
| Tidak ada isolasi / banyak noise | Pastikan `GND_HOST` tidak tersambung ke `GND_ISO` lewat kabel sensor, USB, osiloskop, atau perangkat lain. |
| Nilai skala penuh tidak tepat | Jalankan kalibrasi dua titik dan pastikan sumber uji 0 V/5 V akurat. |
| Modul tidak menyala atau catu turun | Periksa polaritas 5 V, kemampuan arus catu host, kabel pendek, serta beban yang terpasang pada `5V_ISO`. |
| Sensor bekerja tanpa beban tetapi tidak stabil saat terhubung | Periksa arus sensor dan kebutuhan beban minimum konverter; resistor preload RPL1 adalah opsi desain untuk kondisi tertentu. |

## Diagram teknis untuk teknisi

Diagram berikut berguna untuk penelusuran sinyal dan servis, tetapi tidak diperlukan untuk pemasangan normal.

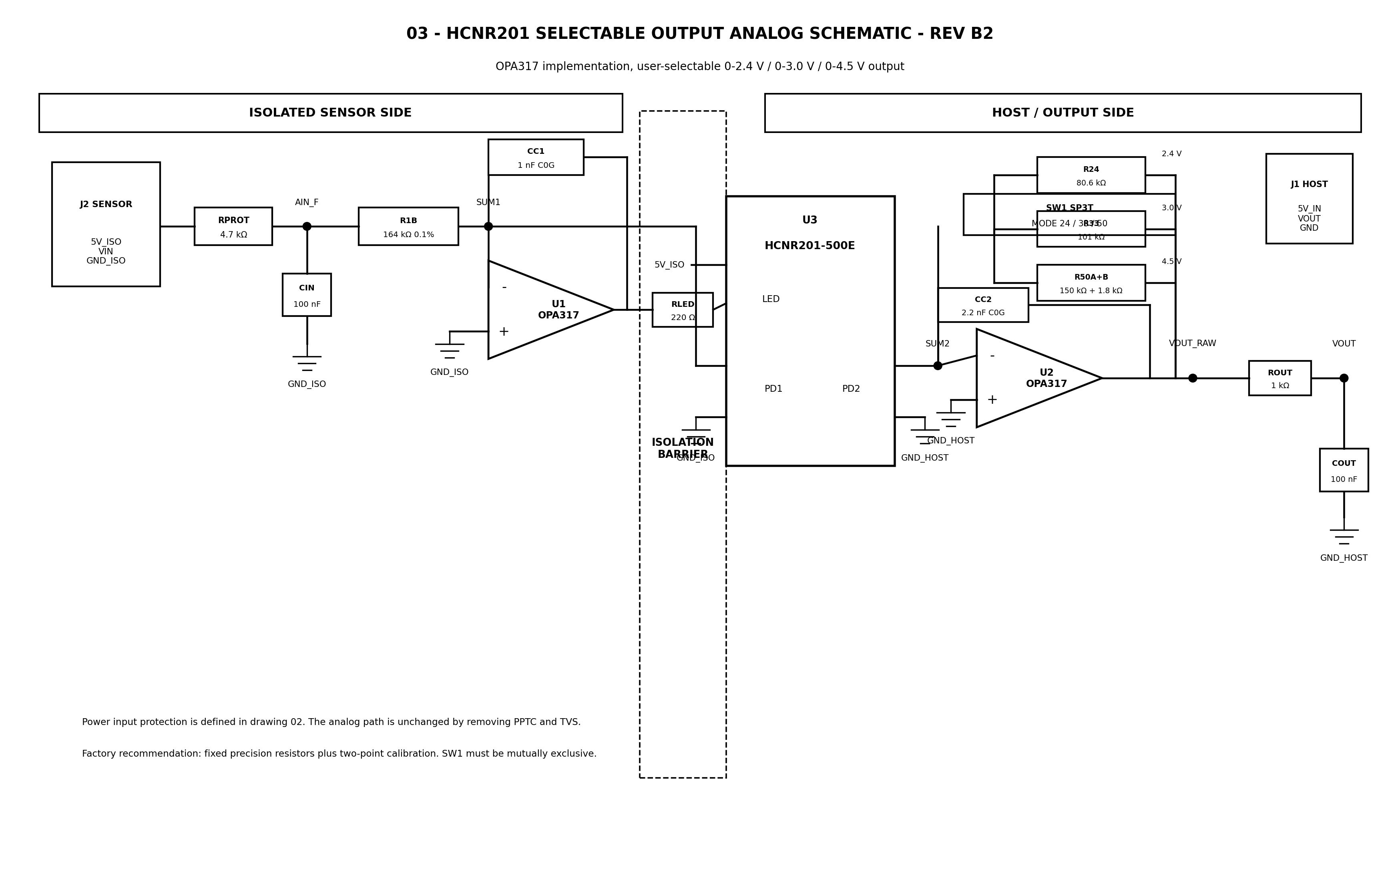
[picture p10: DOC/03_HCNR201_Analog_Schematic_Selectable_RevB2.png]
Skema jalur analog


Jalur catu host menggunakan MOSFET proteksi polaritas dan ferrite bead sebelum konverter DC/DC terisolasi.

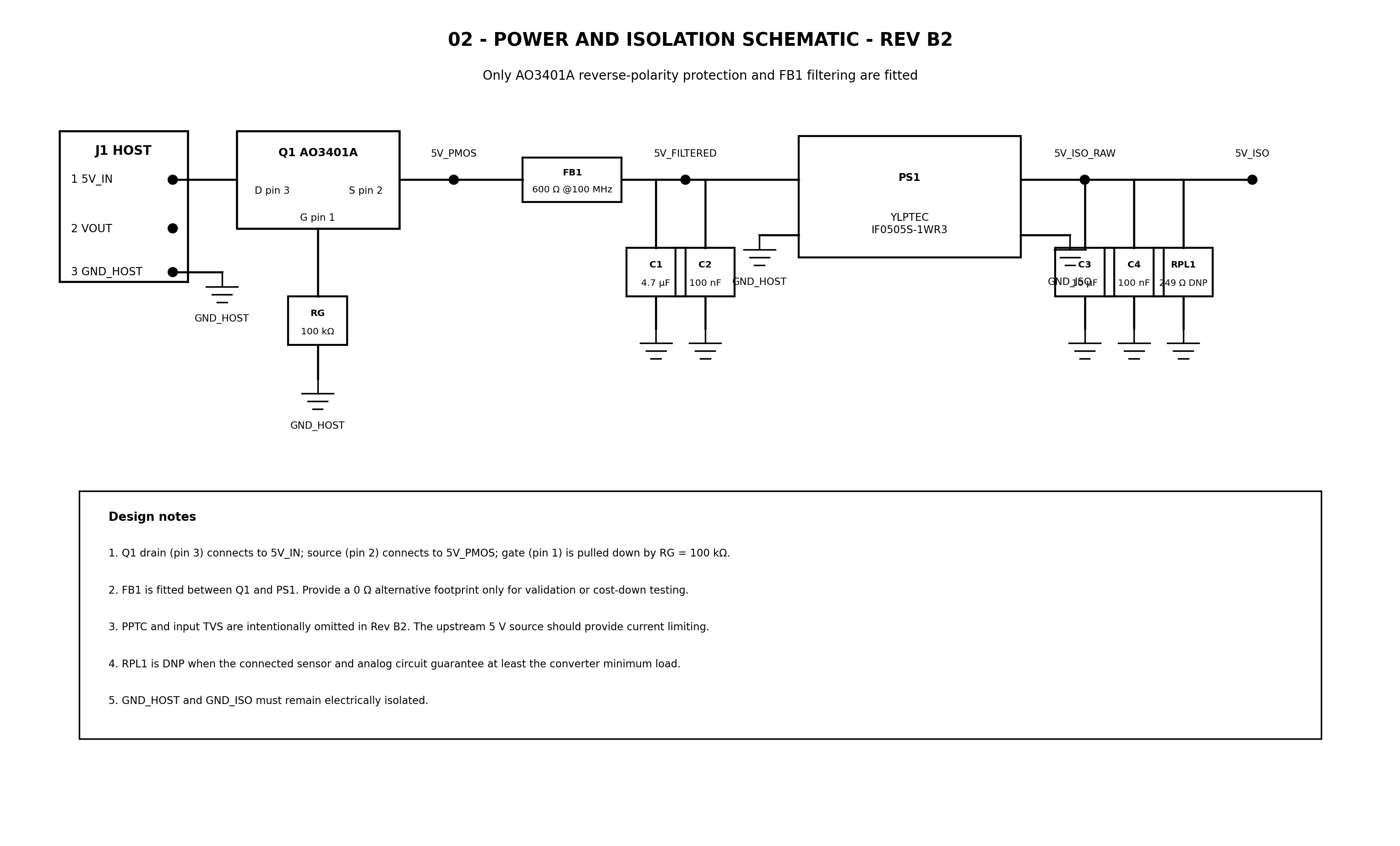
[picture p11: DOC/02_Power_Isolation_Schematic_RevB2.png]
Skema catu dan isolasi


## Isi paket desain

Folder `DOC/` memuat diagram blok, skematik catu dan analog, petunjuk pemilihan mode, pengkabelan, aturan layout PCB, prosedur pengujian, serta BOM. Folder `PCB/` memuat proyek KiCad, Gerber, drill file, footprint, dan model 3D untuk produksi.

Untuk bantuan teknis, sertakan foto pemasangan, mode yang dipilih, tegangan pada J1/J2, serta hasil pengukuran `VIN` dan `VOUT` saat menghubungi penjual/pembuat.

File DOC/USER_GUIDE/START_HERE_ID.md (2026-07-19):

# Mulai di Sini — PCB bertuliskan `AIN` dan `AOUT`

Panduan ini adalah satu-satunya panduan pemasangan untuk PCB pada foto berikut. Ikuti nama pin yang tercetak pada PCB: **`AIN`**, **`AOUT`**, `5V`, dan `GND`.

PCB tampak atas

> [!IMPORTANT]
> Jangan mengikuti istilah `J1`, `J2`, `VIN`, `VOUT`, atau `SW1` dari dokumen Rev B2 lama saat memasang PCB ini. PCB pada foto memakai `AIN/AOUT` dan pemilih mode berupa tiga footprint resistor 0 Ω.

Panduan ini cocok apabila silkscreen PCB Anda memuat semua tulisan berikut: `MCU SIDE`, `SENSOR SIDE`, `AOUT`, `AIN`, dan `FIT ONE ONLY`. Jika tidak, hentikan pemasangan dan minta panduan untuk revisi PCB yang Anda terima.

## Yang perlu disiapkan

1. Satu PCB Analog Signal Isolator yang sudah dirakit (isi paket produk).
2. Catu 5 V DC yang teratur dan memiliki pembatas arus.
3. Sensor dengan output **0–5 V DC** yang sudah dikondisikan.
4. Mikrokontroler/PLC dengan input ADC. Contoh berikut memakai ESP32.
5. Kabel penghubung yang sesuai. Sensor, kabel, catu daya, dan board ESP32 **tidak** termasuk paket.

> [!TIP]
> PCB produk ini sudah dirakit dan dikirim dengan mode ESP32 `M2.4V1` terpasang. Tidak perlu memasang resistor/jumper tambahan untuk penggunaan ESP32.

## Sebelum menghubungkan kabel

Mode bawaan produk sudah `M2.4V1` untuk ESP32. Area `FIT ONE ONLY` hanya dipakai bila konfigurasi perlu diubah saat daya mati oleh teknisi yang memahami perubahan tersebut.

| Perangkat host | Pasang 0 Ω pada | Keluaran pada AIN = 5 V (nominal) |
| --- | --- | ---: |
| ESP32 / ADC 3,3 V yang butuh margin aman | `M2.4V1` **(bawaan, sudah terpasang)** | sekitar 2,4 V |
| ADC kelas 3,3 V | `M3.3V1` | sekitar 3,0 V |
| Arduino 5 V / PLC | `M5V1` | sekitar 4,5 V |

**Jangan pasang dua atau tiga jumper.** Nama `M3.3V1` dan `M5V1` menunjukkan kelas ADC, bukan keluaran tepat 3,3 V atau 5,0 V.

## Batas arus catu sensor

Pin `5V` pada **SENSOR SIDE** boleh memberi daya sensor hingga **150 mA kontinu total**. Batas ini sudah menyisakan arus untuk rangkaian isolator, toleransi, suhu, dan lonjakan saat sensor mulai menyala.

> [!CAUTION]
> Konverter DC/DC pada PCB memiliki rating 5 V / 200 mA, tetapi angka itu adalah rating konverter secara keseluruhan—**bukan** arus yang seluruhnya tersedia untuk sensor. Jangan gunakan `5V` SENSOR SIDE untuk relay, motor, pemanas, atau beban dengan *inrush* besar. Pakai catu terisolasi eksternal untuk beban seperti itu.

## Proteksi catu eksternal (disarankan)

Diagram proteksi catu eksternal

PCB ini tidak memiliki TVS maupun PPTC. Untuk pemasangan di panel atau mesin:

1. Beri catu hanya dari sumber **5 V DC teratur** pada MCU SIDE.
2. Pasang sekering atau PPTC pada kabel `+5V` sebelum PCB. Pilih rating dari arus sistem dan uji arus awal; 250–500 mA dapat dipakai sebagai titik awal desain, lalu disesuaikan hasil uji.
3. Pasang TVS **unidirectional, 5 V working voltage** di antara `+5V` dan `GND` sesudah sekering/PPTC. Pastikan energi surge dan tegangan jepit TVS sesuai dengan lingkungan/catu Anda.
4. Untuk kabel sensor panjang, TVS 5 V terpisah boleh dipasang dari `5V` ke `GND` pada sisi sensor. Jangan pernah memasang TVS atau kabel yang menghubungkan GND sensor dengan GND MCU.

> [!WARNING]
> Proteksi di atas untuk sistem 5 V DC. Untuk petir atau surge energi tinggi, gunakan SPD di pintu masuk panel dan catu yang sesuai. Jangan memakai PCB ini sebagai proteksi petir atau klaim sertifikasi keselamatan.

## Wiring contoh: sensor 0–5 V ke ESP32

Diagram wiring ESP32

| Dari | Ke | Fungsi |
| --- | --- | --- |
| Sensor `VCC` | **SENSOR SIDE** `5V` | Catu sensor 5 V terisolasi |
| Sensor `GND` | **SENSOR SIDE** `GND` | Ground sensor |
| Sensor `OUT` (0–5 V) | **SENSOR SIDE** `AIN` | Sinyal yang akan diisolasi |
| ESP32 `5V` / +5 V catu host | **MCU SIDE** `5V` | Catu masuk modul |
| ESP32 `GND` | **MCU SIDE** `GND` | Ground host |
| Pin ADC ESP32, misalnya GPIO34 | **MCU SIDE** `AOUT` | Sinyal analog terisolasi |

> [!CAUTION]
> `GND` sensor **tidak boleh** disambungkan ke `GND` ESP32. Periksa juga USB, osiloskop, dan perangkat lain karena dapat menyatukan ground secara tidak sengaja.

## Uji pertama dalam 5 menit

1. Matikan catu daya, lalu pastikan jumper bawaan `M2.4V1` masih terpasang untuk ESP32.
2. Hubungkan kabel sesuai tabel di atas.
3. Nyalakan catu +5 V pada **MCU SIDE**.
4. Ukur `AOUT` terhadap `GND` di **MCU SIDE**:

| Kondisi | Hasil yang diharapkan pada mode `M2.4V1` |
| --- | --- |
| `AIN = 0 V` | mendekati 0 V |
| `AIN = 5 V` | sekitar 2,4 V |

5. Jika hasil benar, baca `AOUT` melalui ADC dan lakukan kalibrasi dua titik.

```text
tegangan_sensor = (tegangan_ADC − VZERO) × 5,0 / (VFULL − VZERO)
```

## Contoh kode ESP32 (Arduino)

Contoh ini membaca `AOUT` pada GPIO34 dan mengubahnya kembali menjadi tegangan sensor. Ganti `VZERO` dan `VFULL` dengan hasil pengukuran unit Anda saat `AIN` diberi 0 V dan 5 V.

```cpp
constexpr int PIN_AOUT = 34;       // pilih pin ESP32 yang mendukung ADC
constexpr float VZERO = 0.012f;    // contoh hasil kalibrasi saat AIN = 0 V
constexpr float VFULL = 2.390f;    // contoh hasil kalibrasi saat AIN = 5 V

void setup() {
  Serial.begin(115200);
  analogReadResolution(12);
}

void loop() {
  const float vAout = analogReadMilliVolts(PIN_AOUT) / 1000.0f;
  float vSensor = (vAout - VZERO) * 5.0f / (VFULL - VZERO);
  vSensor = constrain(vSensor, 0.0f, 5.0f);

  Serial.printf("AOUT: %.3f V | Sensor: %.3f V\n", vAout, vSensor);
  delay(500);
}
```

GPIO34 hanya contoh; gunakan pin ADC yang tersedia di papan ESP32 Anda. Jangan menganggap angka kalibrasi contoh di atas sebagai angka bawaan modul.

## Jika tidak bekerja

| Gejala | Periksa |
| --- | --- |
| `AOUT` 0 V terus | Ada +5 V pada MCU SIDE; sensor mendapat +5 V pada SENSOR SIDE; sensor OUT benar-benar 0–5 V terhadap GND sensor. |
| ADC ESP32 selalu maksimum | Pastikan hanya `M2.4V1` yang terpasang dan `AOUT` masuk ke pin ADC, bukan pin digital biasa. |
| Pembacaan bising / isolasi tidak terasa | Cari ground yang tersambung lewat USB, osiloskop, shield kabel, atau catu eksternal. |
| Tidak tahu mode yang terpasang | Produk standar dikirim dengan `M2.4V1`. Bila tampak berbeda, lihat area `FIT ONE ONLY` atau tanyakan kepada penjual sebelum memberi daya. |

## Lanjutkan ke dokumen lain

- [Pinout visual PCB](pinout-pcb.html)
- [Infografik pinout siap dibagikan](assets/pinout-pcb-infographic.png)
- [Referensi teknis Rev B2](README.md) — untuk teknisi; istilah konektor dapat berbeda dengan PCB ini.

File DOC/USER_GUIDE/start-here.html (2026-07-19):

# Mulai di Sini

Untuk PCB Analog Signal Isolator yang bertuliskan AIN dan AOUT.

Gunakan nama pin di PCB ini. Produk berisi satu PCB yang sudah dirakit; mode ESP32 M2.4V1 sudah terpasang. Sensor, kabel, catu daya, dan board ESP32 tidak termasuk. Jangan memakai petunjuk J1/J2, VIN/VOUT, atau SW1 dari dokumen Rev B2 lama untuk memasang PCB AIN/AOUT ini. Panduan ini hanya untuk PCB bertuliskan MCU SIDE, SENSOR SIDE, AIN, AOUT, dan FIT ONE ONLY.

## 1. Pastikan PCB Anda sama

Tampak atas PCB AIN AOUT

MCU SIDE: AOUT, GND, 5V. SENSOR SIDE: AIN, GND, 5V.

## 2. Mode ESP32 sudah siap

Host | Jumper 0 Ω yang dipasang | AOUT pada AIN = 5 V
ESP32 | M2.4V1 (bawaan, sudah terpasang) | sekitar 2,4 V
ADC 3,3 V | M3.3V1 | sekitar 3,0 V
Arduino 5 V / PLC | M5V1 | sekitar 4,5 V

Area ini bertuliskan FIT ONE ONLY. Untuk ESP32, biarkan M2.4V1 terpasang. Jangan memasang lebih dari satu jumper.

## 3. Hubungkan seperti contoh ESP32 ini

Diagram wiring sensor melalui modul ke ESP32

Sensor OUT ke AIN, pin ADC ESP32 ke AOUT, dan kedua ground tetap terpisah.

Jangan menyatukan ground. GND sensor hanya ke SENSOR SIDE. GND ESP32 hanya ke MCU SIDE. Lepaskan hubungan yang tidak disengaja melalui USB, osiloskop, atau catu lain.

## Batas catu sensor

Pin 5V pada SENSOR SIDE untuk sensor hingga 150 mA kontinu total. Rating DC/DC 200 mA mencakup konsumsi modul dan bukan arus sensor yang tersedia penuh. Jangan gunakan keluaran ini untuk relay, motor, pemanas, atau beban dengan lonjakan arus besar; gunakan catu terisolasi eksternal.

## Proteksi catu eksternal

Diagram sekering PPTC dan TVS eksternal pada catu isolator

Proteksi dipasang di luar PCB dan tetap menjaga kedua ground terpisah.

Gunakan catu 5 V DC teratur. Pasang sekering/PPTC pada jalur +5 V sebelum MCU SIDE (pilih berdasarkan arus sistem; 250–500 mA hanya titik awal desain), lalu TVS unidirectional dengan tegangan kerja 5 V dari +5 V ke GND sesudahnya. Untuk kabel sensor panjang, TVS 5 V terpisah boleh dipasang dari 5 V ke GND SENSOR saja.

Jangan memasang TVS, kabel, atau ground yang melintasi penghalang isolasi. Untuk petir/surge energi tinggi, gunakan SPD pada masuknya panel dan catu yang sesuai.

## 4. Uji dan baca dengan ESP32

Dengan mode ESP32 (M2.4V1), AOUT harus mendekati 0 V saat AIN = 0 V dan sekitar 2,4 V saat AIN = 5 V. Setelah itu lakukan kalibrasi dua titik.

constexpr int PIN_AOUT = 34;
constexpr float VZERO = 0.012f; // ukur sendiri pada AIN = 0 V
constexpr float VFULL = 2.390f; // ukur sendiri pada AIN = 5 V

float vAout = analogReadMilliVolts(PIN_AOUT) / 1000.0f;
float vSensor = (vAout - VZERO) * 5.0f / (VFULL - VZERO);

GPIO34 hanya contoh; gunakan pin ADC yang tersedia di papan ESP32 Anda. Buka panduan lengkap dan kode lengkap →

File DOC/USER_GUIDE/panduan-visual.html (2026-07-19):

# Analog Signal Isolator

Panduan pemasangan dan penggunaan untuk modul isolator sinyal 0–5 V — Rev B2.

Penting. Modul ini untuk sinyal elektronik bertegangan rendah. Bukan alat ukur langsung listrik PLN, bukan pernyataan sertifikasi keselamatan, dan bukan pengganti proteksi petir/surge.

Referensi teknik Rev B2. Halaman ini memakai istilah J1/J2, VIN/VOUT, dan SW1. Untuk PCB fisik bertuliskan AIN/AOUT, gunakan Mulai di Sini; halaman tersebut adalah panduan utama pembeli.

## Apa fungsi modul ini?

Modul memisahkan sisi sensor dari sisi mikrokontroler/PLC secara galvanik. Sensor mengirim sinyal DC 0–5 V melalui VIN; host menerima versi terisolasi di VOUT. Ground sensor dan ground host tidak boleh disatukan.

Diagram blok Analog Signal Isolator

Alur sinyal dari sensor terisolasi menuju host/MCU.

## Spesifikasi utama

Input sensor0–5,0 V DC yang sudah dikondisikan.

Catu host5 V DC teratur, disarankan memiliki pembatas arus.

Mode keluaran2,4 V, 3,0 V, atau 4,5 V nominal.

PenggunaanSensor DC/lambat; input mulai teredam sekitar 339 Hz.

Modul bukan input 4–20 mA, bukan input AC, dan tidak boleh diberi sinyal negatif atau lebih dari 5 V tanpa rangkaian pengondisi tambahan.

## Wiring

Diagram konektor J1 host dan J2 sensor

Hubungkan host pada J1 dan sensor pada J2 seperti gambar.

Konektor | Pin | Fungsi
J1 — HOST | 1: 5V_IN | Catu host +5 V
J1 — HOST | 2: VOUT | Ke ADC/input analog host
J1 — HOST | 3: GND_HOST | Ground host/MCU/PLC
J2 — SENSOR | 1: 5V_ISO | +5 V terisolasi untuk sensor
J2 — SENSOR | 2: VIN | Sinyal sensor 0–5 V
J2 — SENSOR | 3: GND_ISO | Ground sensor

## Pilih mode sebelum menyalakan daya

Diagram mode keluaran 24, 33 dan 50

SW1 adalah pemilih tunggal: aktifkan hanya satu mode.

Mode | Keluaran skala penuh nominal | Penggunaan yang dianjurkan
MODE 24 | 2,4 V | ESP32 atau ADC 3,3 V yang memerlukan margin aman
MODE 33 | 3,0 V | ADC MCU 3,3 V umum
MODE 50 | 4,5 V | ADC 5 V, Arduino 5 V, atau PLC

## Pasang dalam 8 langkah

1. Matikan seluruh catu daya dan pilih mode SW1.
2. Pastikan keluaran sensor adalah 0–5 V DC.
3. Hubungkan 5V_IN, VOUT, dan GND_HOST pada J1.
4. Hubungkan sensor ke 5V_ISO, VIN, dan GND_ISO pada J2.
5. Pastikan tidak ada hubungan antara GND_HOST dan GND_ISO.
6. Nyalakan catu host +5 V yang memiliki pembatas arus.
7. Uji input 0 V dan 5 V; periksa apakah VOUT mendekati skala penuh mode.
8. Lakukan kalibrasi dua titik sebelum penggunaan presisi.

## Pinout berdasarkan PCB fisik

PCB tampak atas dengan sisi MCU dan sensor

MCU SIDE: AOUT, GND, 5V. SENSOR SIDE: AIN, GND, 5V. Ikuti label silkscreen di PCB.

PCB pada foto memakai jumper solder M2.4V1, M3.3V1, dan M5V1. Pasang satu saja (FIT ONE ONLY). Detail pemasangan tersedia dalam dokumen pinout PCB.

PCB tampak bawah

Jangan membuat hubungan konduktif melintasi celah isolasi di tengah PCB.

## Kalibrasi dua titik

Catat VZERO pada VIN = 0 V dan VFULL pada VIN = 5 V. Untuk setiap pembacaan ADC, gunakan:

VIN = (VMEAS − VZERO) × 5,0 / (VFULL − VZERO)

Simpan nilai kalibrasi untuk tiap unit dan tiap mode. Kalibrasi ini hanya untuk jalur isolator; kalibrasi fisik sensor dilakukan terpisah.

## Catatan keandalan dan troubleshooting

- Rev B2 tidak memiliki TVS atau sekering resettable pada papan; proteksi surge dan pembatas arus harus disediakan oleh sistem.
- Jika output 0 V, periksa catu J1, catu sensor J2, lalu tegangan VIN terhadap GND_ISO.
- Jika pembacaan bising, cari sambungan ground tak sengaja melalui USB, osiloskop, atau kabel sensor.
- Jika skala penuh meleset, jangan mengubah switch; lakukan kalibrasi dua titik dengan sumber uji yang akurat.

Skematik jalur analog HCNR201

Referensi teknis jalur analog untuk troubleshooting tingkat lanjut.

Analog Signal Isolator · Rev B2 · Buka file ini di browser agar seluruh gambar tampil.

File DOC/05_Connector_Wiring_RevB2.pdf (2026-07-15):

# 05 - CONNECTOR WIRING - REV B2

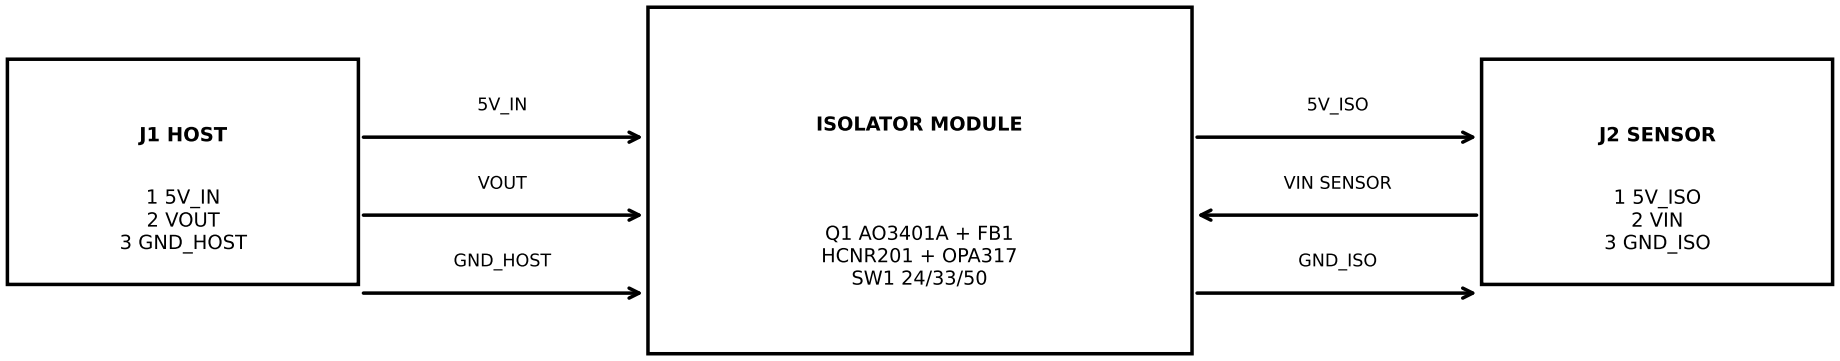
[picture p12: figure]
J1 HOST; 1 5V_IN 2 VOUT 3 GND_HOST; J2 SENSOR; 1 5V_ISO 2 VIN 3 GND_ISO; ISOLATOR MODULE; Q1 AO3401A + FB1 HCNR201 + OPA317 SW1 24/33/50; VOUT; GND_HOST; 5V_ISO; VIN SENSOR; GND_ISO

## Installation requirements

Use a regulated/current-limited 5 V host supply. Rev B2 has no on-board PPTC and no input TVS.

Do not connect GND_HOST to GND_ISO. The sensor must be powered from J2 pin 1 and J2 pin 3.

Select MODE 24, MODE 33, or MODE 50 before operation. Do not modify the switch while calibrating.

Host-side ADC clamp protection remains the responsibility of the host board.

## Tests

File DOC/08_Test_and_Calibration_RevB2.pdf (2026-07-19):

### 08 Test and Calibration - Rev B2

Rev B2 - Page 1

# 08 - Test and Calibration - Rev B2

# Bring-up and production tests

Step | Procedure | Pass criterion
1 | Inspect Q1 orientation, RG value, FB1 fitment, and absence of PPTC/TVS.Assembly matches Rev B2 schematic.
2 | With power off, verify no continuity between GND_HOST and GND_ISO. | Open circuit / high resistance.
3 | Apply +5 V with current-limited supply. Measure voltage before and after Q1 and FB1. PMOS drop remains small; PS1 input remains within valid range.
4 | Apply reverse polarity briefly using a current-limited supply. | No power reaches PS1; no damage or overheating.
5 | Measure 5V_ISO with sensor disconnected and connected. | Rail remains stable; fit RPL1 only if minimum-load behavior requires it.
6 | Set VIN to 0 V and 5 V in each SW1 mode. | Outputs are near 0/2.4 V, 0/3.0 V, and 0/4.5 V respectively.
7 | Measure output noise and PS1 ripple with FB1 fitted. | Noise satisfies the product target; compare against 0 Ω only during validation.
8 | Store zero and full-scale calibration values for each unit or selected mode.Firmware reconstructs the 0-5 V sensor input correctly.

# Calibration formula

For each mode, record VZERO at VIN = 0.000 V and VFULL at VIN = 5.000 V. The reconstructed input voltage is VIN = (VMEAS - VZERO) x 5.0 / (VFULL - VZERO). This calibration belongs to the analog isolator and is separate from the sensor's physical calibration.

# Safety boundary

Rev B2 does not claim surge immunity from an on-board TVS and does not provide a self-resetting input fuse. Use it with a controlled 5 V source and short wiring, or add protection at the system level.

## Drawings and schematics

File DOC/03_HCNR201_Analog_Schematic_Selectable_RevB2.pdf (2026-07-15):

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

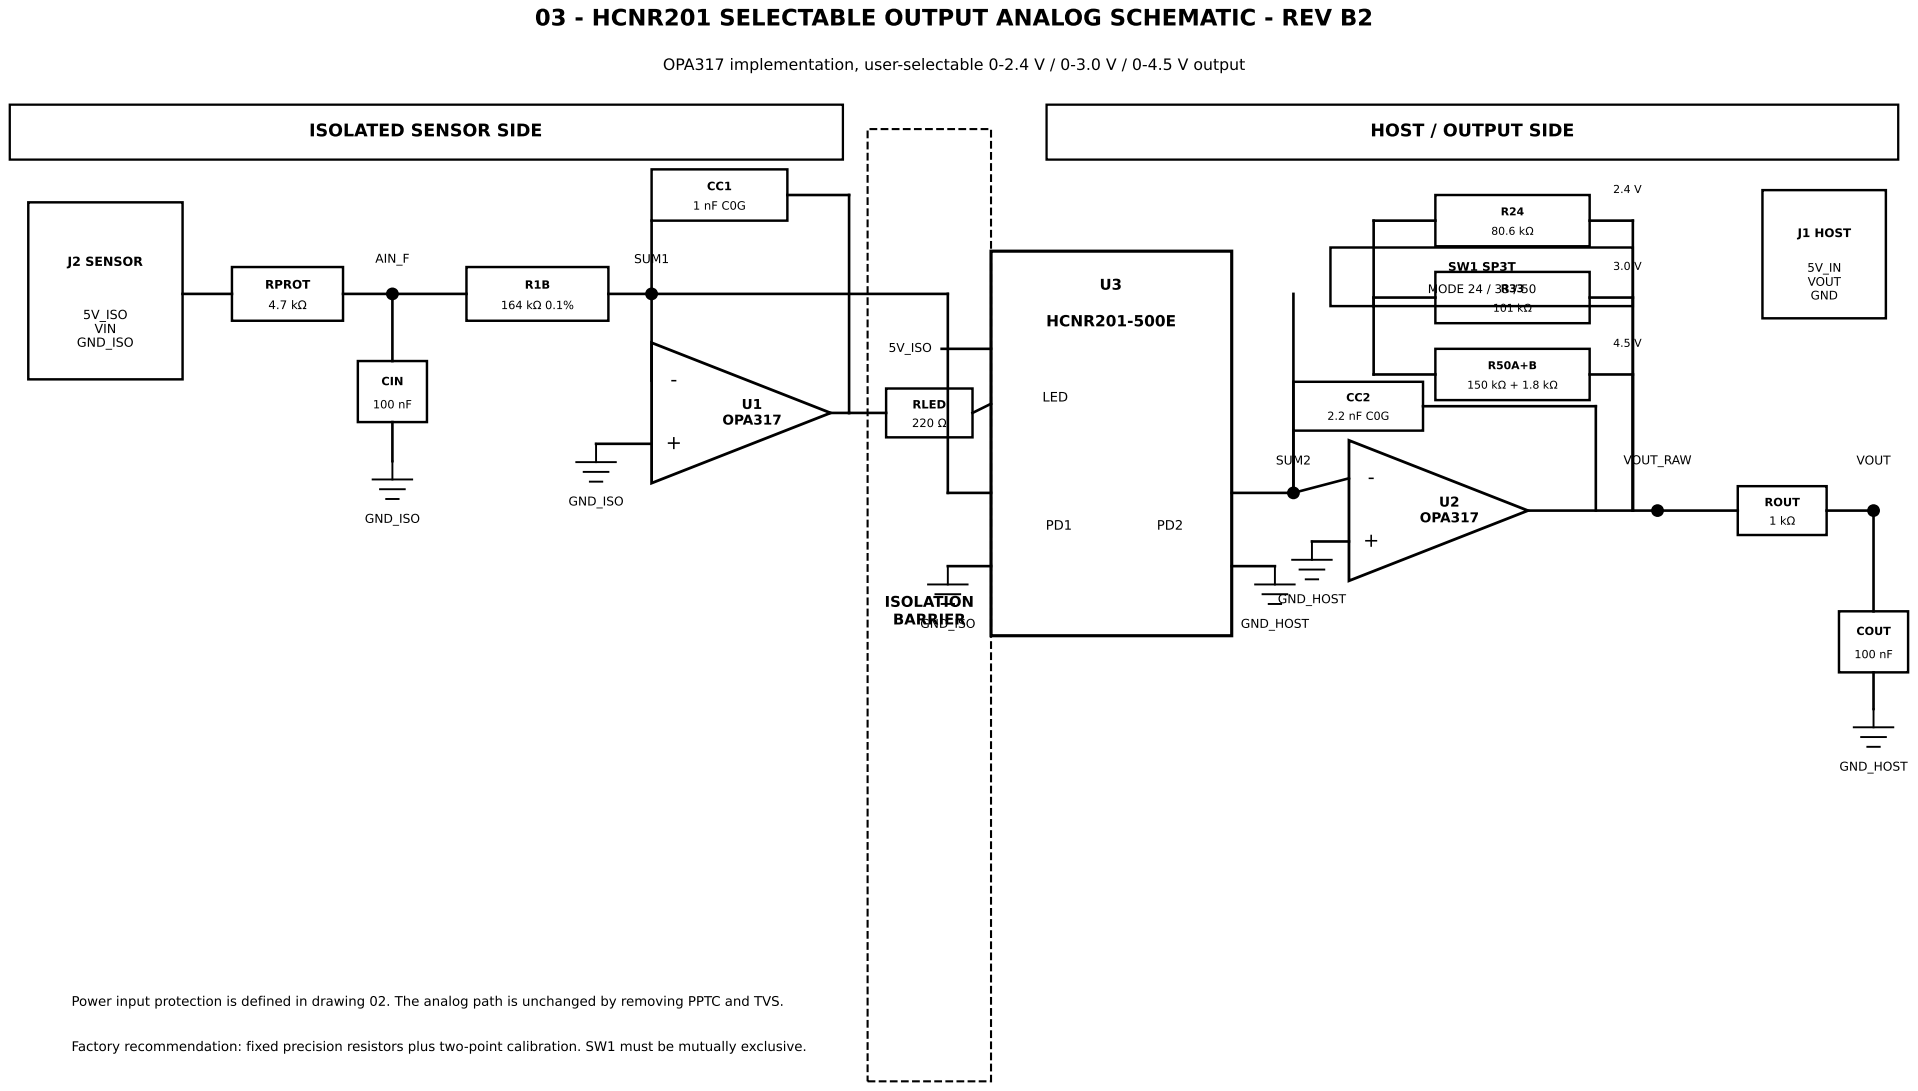
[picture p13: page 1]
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

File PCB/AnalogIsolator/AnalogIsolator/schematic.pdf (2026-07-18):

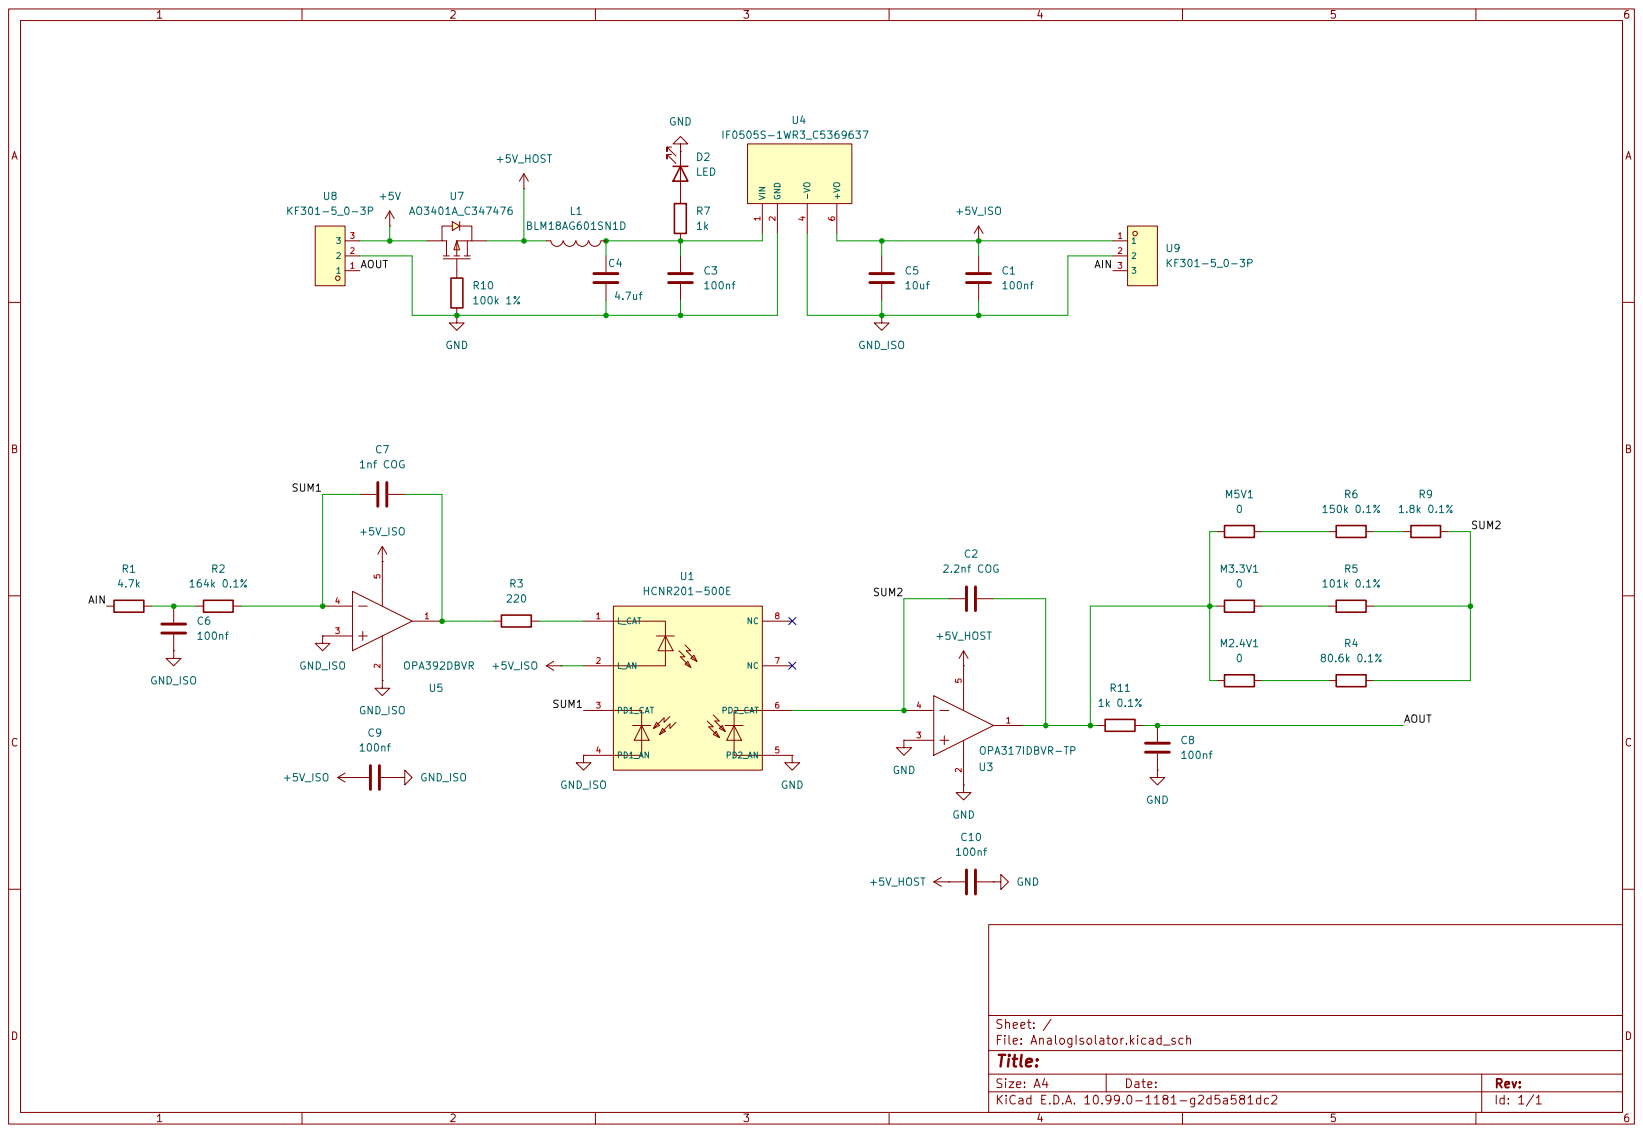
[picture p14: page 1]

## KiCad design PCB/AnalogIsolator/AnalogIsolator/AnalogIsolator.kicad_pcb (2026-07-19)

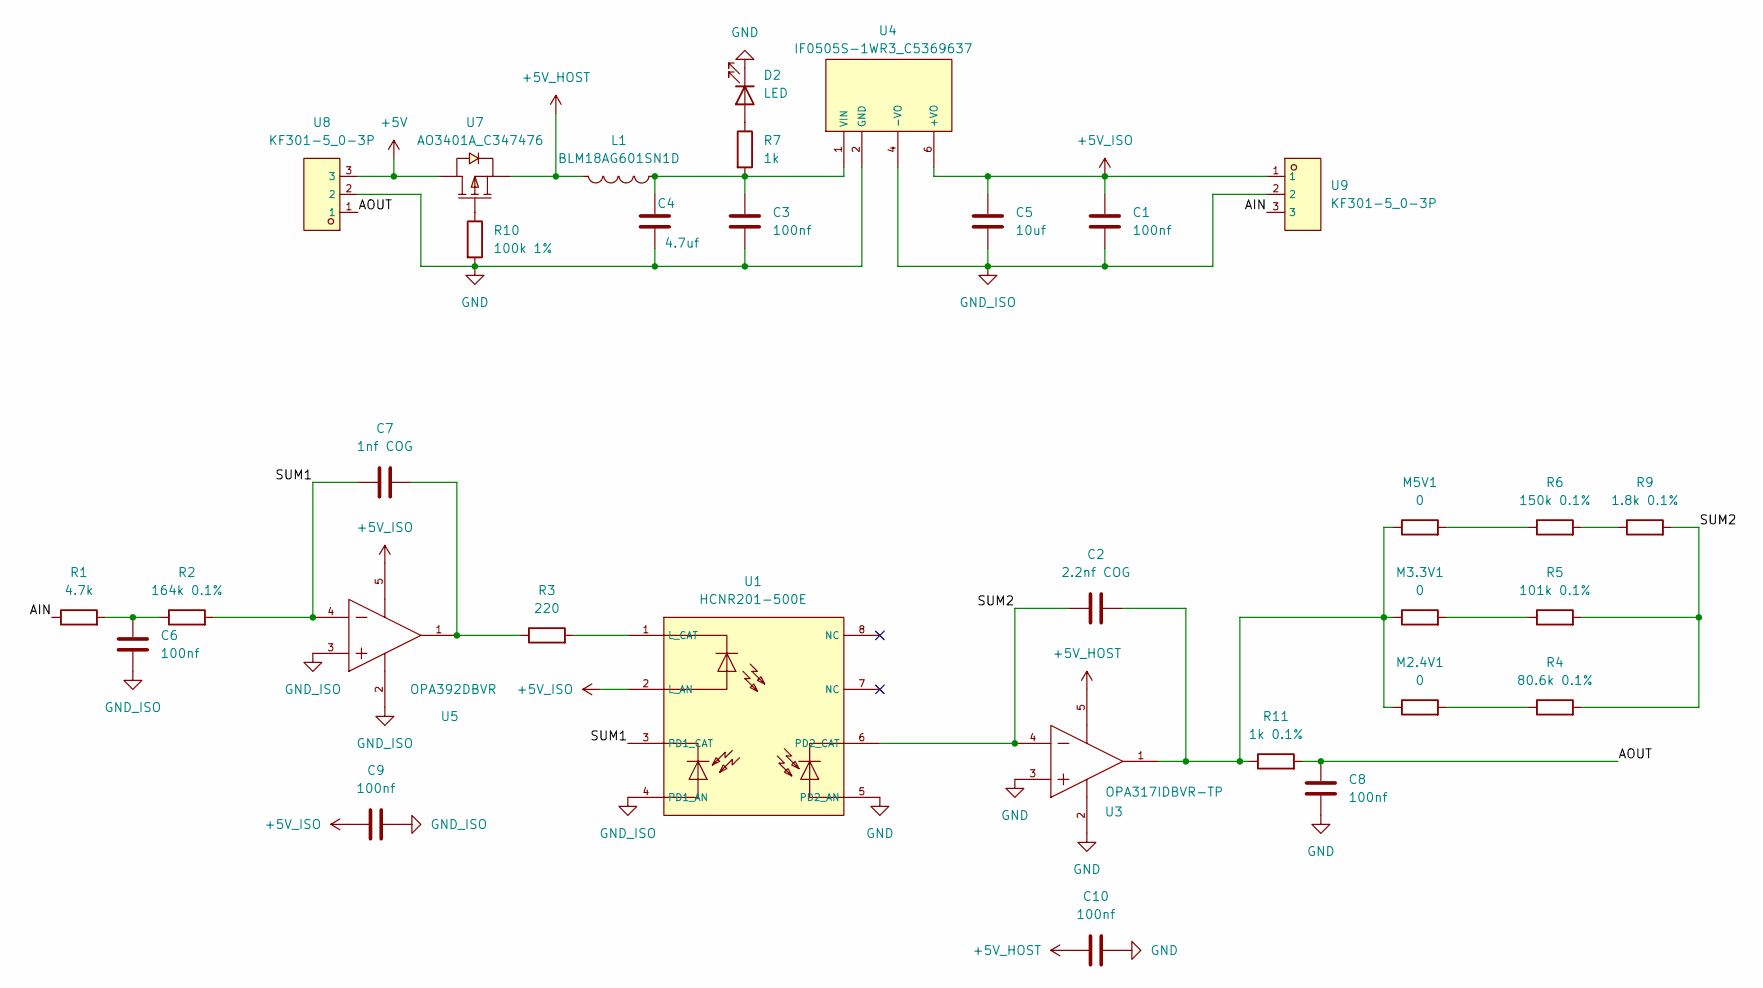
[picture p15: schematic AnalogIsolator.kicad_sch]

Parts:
C1, C3, C6, C8, C9, C10: 100nf; C_0603_1608Metric
C2: 2.2nf COG; C_0603_1608Metric
C4: 4.7uf; C_0603_1608Metric
C5: 10uf; C_0805_2012Metric
C7: 1nf COG; C_0603_1608Metric
D2: LED
L1: BLM18AG601SN1D; L0603; LCSC C19330
M2.4V1, M3.3V1, M5V1: 0; R_0603_1608Metric
R1: 4.7k; R_0603_1608Metric
R2: 164k 0.1%; R_0603_1608Metric
R3: 220; R_0603_1608Metric
R4: 80.6k 0.1%; R_0805_2012Metric
R5: 101k 0.1%; R_0805_2012Metric
R6: 150k 0.1%; R_0805_2012Metric
R7: 1k; R_0603_1608Metric
R9: 1.8k 0.1%; R_0805_2012Metric
R10: 100k 1%; R_0603_1608Metric
R11: 1k 0.1%; R_0603_1608Metric
U1: HCNR201-500E; OPTO-SMD-8P_L11.0-W9.0-P2.54-LS12.4-BL; LCSC C27465
U3: OPA317IDBVR-TP; SOT-23-5_L2.9-W1.6-P0.95-LS2.8-BR; LCSC C41431830
U4: IF0505S-1WR3_C5369637; PWRM-TH_BXXXXLS-1W; LCSC C5369637
U5: OPA392DBVR; SOT-23-5_L2.9-W1.6-P0.95-LS2.8-BL; LCSC C3647166
U7: AO3401A_C347476; SOT-23_L2.9-W1.3-P1.90-LS2.4-BR; LCSC C347476
U8, U9: KF301-5_0-3P; CONN-TH_3P-P5.00_KF301-5.0-3P; LCSC C474882

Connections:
+5V: U7.3 (D), U8.3
+5V_HOST: C10.1, L1.1, U3.5 (V+), U7.2 (S)
+5V_ISO: C1.1, C5.1, C9.1, U1.2 (L_AN), U4.6 (+VO), U5.5 (V+), U9.1
/AIN: R1.1, U9.3
/AOUT: C8.1, R11.2, U8.1
/SUM1: C7.1, R2.2, U1.3 (PD1_CAT), U5.4 (IN_-)
/SUM2: C2.1, R4.2, R5.2, R9.2, U1.6 (PD2_CAT), U3.4 (-IN)
GND: C3.2, C4.2, C8.2, C10.2, D2.1 (K), R10.2, U1.5 (PD2_AN), U3.2 (V-), U3.3 (+IN), U4.2 (GND), U8.2
GND_ISO: C1.2, C5.2, C6.2, C9.2, U1.4 (PD1_AN), U4.4 (-VO), U5.2 (V-), U5.3 (IN_+), U9.2
unnamed: C6.1, R1.2, R2.1
unnamed: D2.2 (A), R7.1
unnamed: M2.4V1.2, R4.1
unnamed: M3.3V1.2, R5.1
unnamed: M5V1.2, R6.1
unnamed: R6.2, R9.1
unnamed: R3.2, U1.1 (L_CAT)
unnamed: C2.2, M2.4V1.1, M3.3V1.1, M5V1.1, R11.1, U3.1 (OUT)
unnamed: C3.1, C4.1, L1.2, R7.2, U4.1 (VIN)
unnamed: C7.2, R3.1, U5.1 (OUT)
unnamed: R10.1, U7.1 (G)

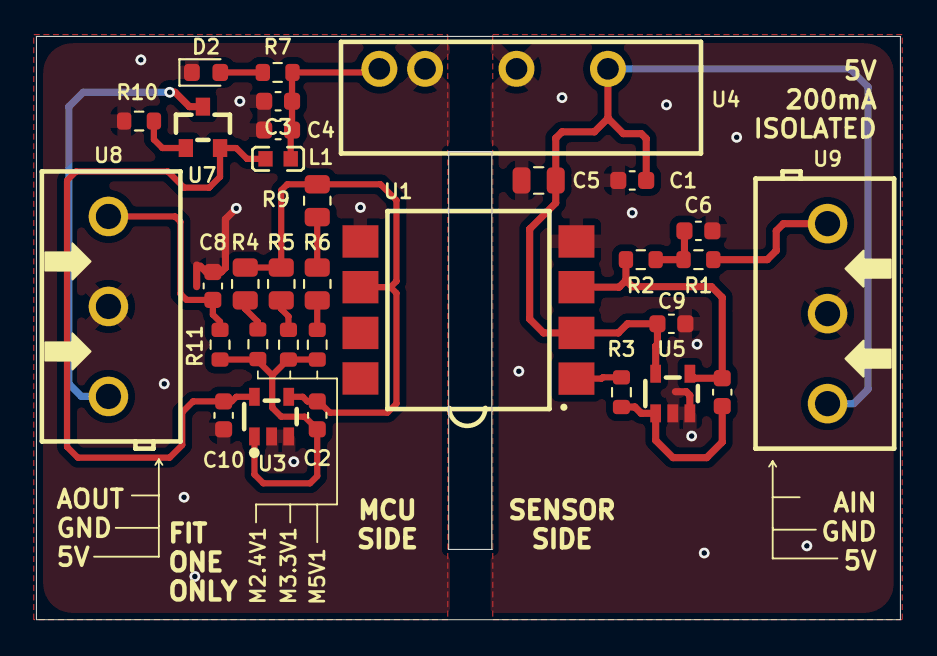
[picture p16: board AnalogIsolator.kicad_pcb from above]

Board: 2 copper layers, 48.0 x 32.4 mm, 32 parts (0 on the bottom side), 20 nets.

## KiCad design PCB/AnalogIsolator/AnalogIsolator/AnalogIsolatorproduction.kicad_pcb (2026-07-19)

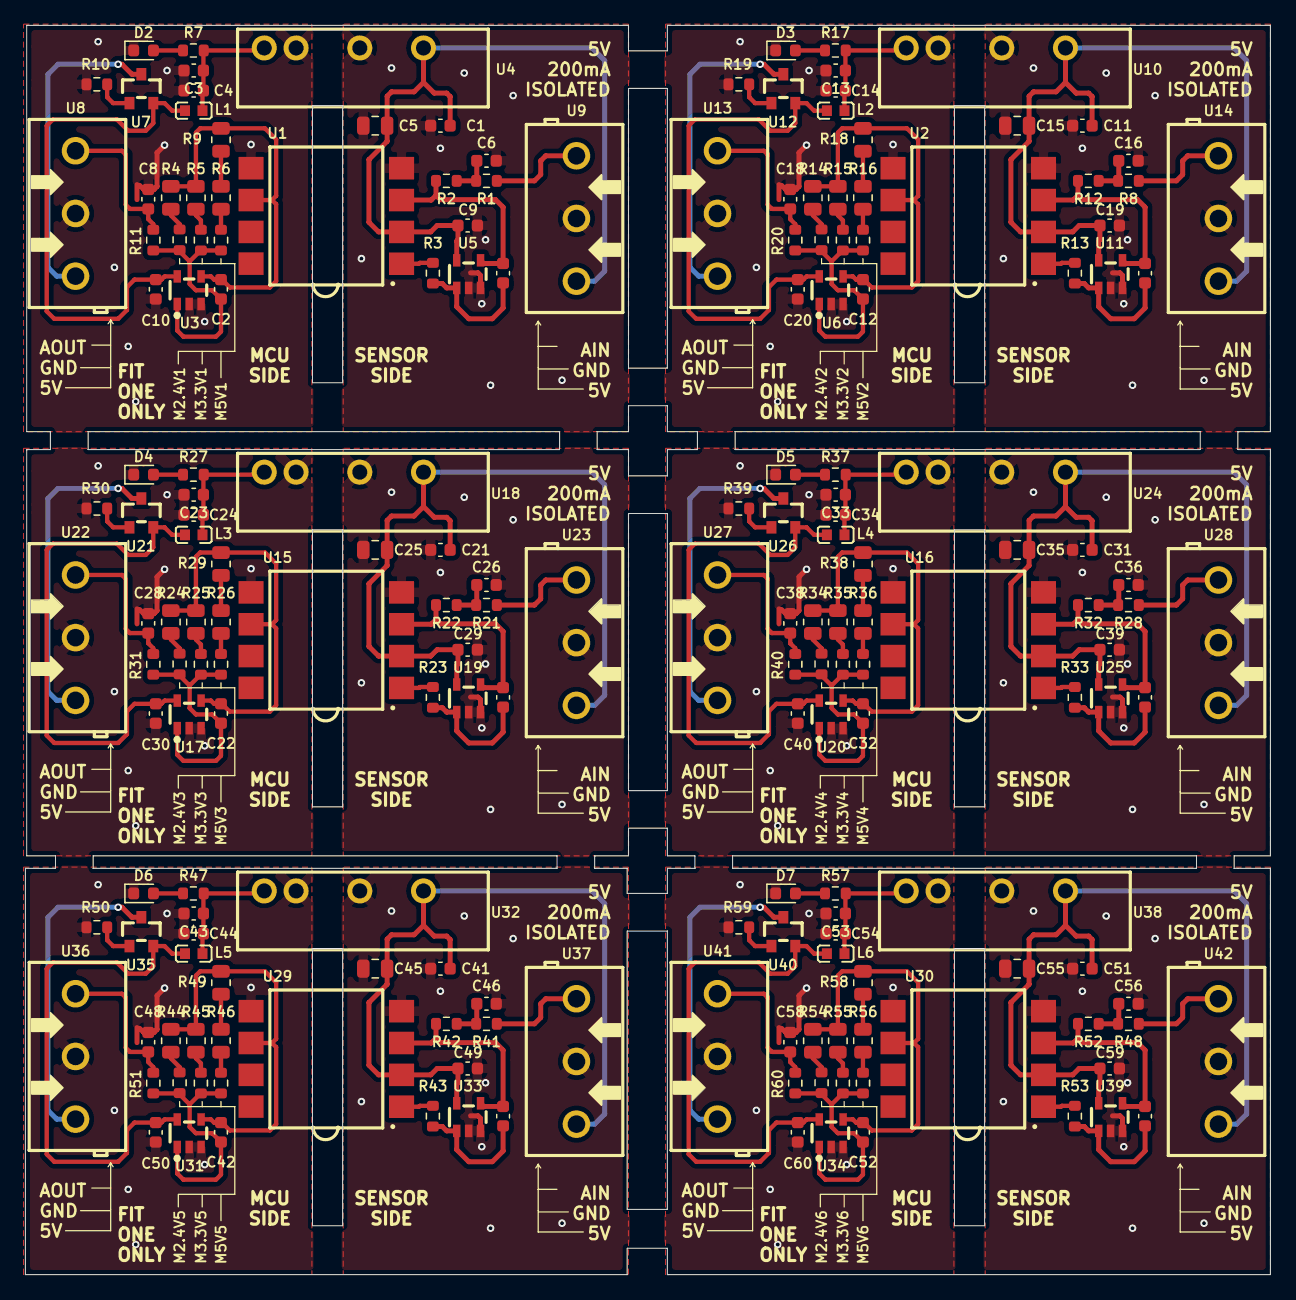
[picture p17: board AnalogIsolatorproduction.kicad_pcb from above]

Board: 2 copper layers, 99.3 x 99.6 mm, 192 parts (0 on the bottom side), 20 nets.

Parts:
C1, C3, C6, C8, C9, C10, C11, C13, C16, C18, C19, C20, C21, C23, C26, C28, C29, C30, C31, C33, C36, C38, C39, C40, C41, C43, C46, C48, C49, C50, C51, C53, C56, C58, C59, C60: 100nf; C_0603_1608Metric
C2, C12, C22, C32, C42, C52: 2.2nf COG; C_0603_1608Metric
C4, C14, C24, C34, C44, C54: 4.7uf; C_0603_1608Metric
C5, C15, C25, C35, C45, C55: 10uf; C_0805_2012Metric
C7, C17, C27, C37, C47, C57: 1nf COG; C_0603_1608Metric
D2, D3, D4, D5, D6, D7: LED; LED_0603_1608Metric
L1, L2, L3, L4, L5, L6: BLM18AG601SN1D; L0603
M2.4V1, M2.4V2, M2.4V3, M2.4V4, M2.4V5, M2.4V6, M3.3V1, M3.3V2, M3.3V3, M3.3V4, M3.3V5, M3.3V6, M5V1, M5V2, M5V3, M5V4, M5V5, M5V6: 0; R_0603_1608Metric
R1, R8, R21, R28, R41, R48: 4.7k; R_0603_1608Metric
R2, R12, R22, R32, R42, R52: 164k 0.1%; R_0603_1608Metric
R3, R13, R23, R33, R43, R53: 220; R_0603_1608Metric
R4, R14, R24, R34, R44, R54: 80.6k 0.1%; R_0805_2012Metric
R5, R15, R25, R35, R45, R55: 101k 0.1%; R_0805_2012Metric
R6, R16, R26, R36, R46, R56: 150k 0.1%; R_0805_2012Metric
R7, R17, R27, R37, R47, R57: 1k; R_0603_1608Metric
R9, R18, R29, R38, R49, R58: 1.8k 0.1%; R_0805_2012Metric
R10, R19, R30, R39, R50, R59: 100k 1%; R_0603_1608Metric
R11, R20, R31, R40, R51, R60: 1k 0.1%; R_0603_1608Metric
U1, U2, U15, U16, U29, U30: HCNR201-500E; OPTO-SMD-8P_L11.0-W9.0-P2.54-LS12.4-BL
U3, U6, U17, U20, U31, U34: OPA317IDBVR-TP; SOT-23-5_L2.9-W1.6-P0.95-LS2.8-BR
U4, U10, U18, U24, U32, U38: IF0505S-1WR3_C5369637; PWRM-TH_BXXXXLS-1W
U5, U11, U19, U25, U33, U39: OPA392DBVR; SOT-23-5_L2.9-W1.6-P0.95-LS2.8-BL
U7, U12, U21, U26, U35, U40: AO3401A_C347476; SOT-23_L2.9-W1.3-P1.90-LS2.4-BR
U8, U9, U13, U14, U22, U23, U27, U28, U36, U37, U41, U42: KF301-5_0-3P; CONN-TH_3P-P5.00_KF301-5.0-3P

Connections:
+5V: U7.3 (D), U8.3, U12.3 (D), U13.3, U21.3 (D), U22.3, U26.3 (D), U27.3, U35.3 (D), U36.3, U40.3 (D), U41.3
+5V_HOST: C10.1, C20.1, C30.1, C40.1, C50.1, C60.1, L1.1, L2.1, L3.1, L4.1, L5.1, L6.1, U3.5 (V+), U6.5 (V+), U7.2 (S), U12.2 (S), U17.5 (V+), U20.5 (V+), U21.2 (S), U26.2 (S), U31.5 (V+), U34.5 (V+), U35.2 (S), U40.2 (S)
+5V_ISO: C1.1, C5.1, C9.1, C11.1, C15.1, C19.1, C21.1, C25.1, C29.1, C31.1, C35.1, C39.1, C41.1, C45.1, C49.1, C51.1, C55.1, C59.1, U1.2 (L_AN), U2.2 (L_AN), U4.6 (+VO), U5.5 (V+), U9.1, U10.6 (+VO), U11.5 (V+), U14.1, U15.2 (L_AN), U16.2 (L_AN), U18.6 (+VO), U19.5 (V+), U23.1, U24.6 (+VO), U25.5 (V+), U28.1, U29.2 (L_AN), U30.2 (L_AN), U32.6 (+VO), U33.5 (V+), U37.1, U38.6 (+VO), U39.5 (V+), U42.1
/AIN: R1.1, R8.1, R21.1, R28.1, R41.1, R48.1, U9.3, U14.3, U23.3, U28.3, U37.3, U42.3
/AOUT: C8.1, C18.1, C28.1, C38.1, C48.1, C58.1, R11.2, R20.2, R31.2, R40.2, R51.2, R60.2, U8.1, U13.1, U22.1, U27.1, U36.1, U41.1
/SUM1: C7.1, C17.1, C27.1, C37.1, C47.1, C57.1, R2.2, R12.2, R22.2, R32.2, R42.2, R52.2, U1.3 (PD1_CAT), U2.3 (PD1_CAT), U5.4 (IN_-), U11.4 (IN_-), U15.3 (PD1_CAT), U16.3 (PD1_CAT), U19.4 (IN_-), U25.4 (IN_-), U29.3 (PD1_CAT), U30.3 (PD1_CAT), U33.4 (IN_-), U39.4 (IN_-)
/SUM2: C2.1, C12.1, C22.1, C32.1, C42.1, C52.1, R4.2, R5.2, R9.2, R14.2, R15.2, R18.2, R24.2, R25.2, R29.2, R34.2, R35.2, R38.2, R44.2, R45.2, R49.2, R54.2, R55.2, R58.2, U1.6 (PD2_CAT), U2.6 (PD2_CAT), U3.4 (-IN), U6.4 (-IN), U15.6 (PD2_CAT), U16.6 (PD2_CAT), U17.4 (-IN), U20.4 (-IN), U29.6 (PD2_CAT), U30.6 (PD2_CAT), U31.4 (-IN), U34.4 (-IN)
GND: C3.2, C4.2, C8.2, C10.2, C13.2, C14.2, C18.2, C20.2, C23.2, C24.2, C28.2, C30.2, C33.2, C34.2, C38.2, C40.2, C43.2, C44.2, C48.2, C50.2, C53.2, C54.2, C58.2, C60.2, D2.1 (K), D3.1 (K), D4.1 (K), D5.1 (K), D6.1 (K), D7.1 (K), R10.2, R19.2, R30.2, R39.2, R50.2, R59.2, U1.5 (PD2_AN), U2.5 (PD2_AN), U3.2 (V-), U3.3 (+IN), U4.2 (GND), U6.2 (V-), U6.3 (+IN), U8.2, U10.2 (GND), U13.2, U15.5 (PD2_AN), U16.5 (PD2_AN), U17.2 (V-), U17.3 (+IN), U18.2 (GND), U20.2 (V-), U20.3 (+IN), U22.2, U24.2 (GND), U27.2, U29.5 (PD2_AN), U30.5 (PD2_AN), U31.2 (V-), U31.3 (+IN), U32.2 (GND), U34.2 (V-), U34.3 (+IN), U36.2, U38.2 (GND), U41.2
GND_ISO: C1.2, C5.2, C6.2, C9.2, C11.2, C15.2, C16.2, C19.2, C21.2, C25.2, C26.2, C29.2, C31.2, C35.2, C36.2, C39.2, C41.2, C45.2, C46.2, C49.2, C51.2, C55.2, C56.2, C59.2, U1.4 (PD1_AN), U2.4 (PD1_AN), U4.4 (-VO), U5.2 (V-), U5.3 (IN_+), U9.2, U10.4 (-VO), U11.2 (V-), U11.3 (IN_+), U14.2, U15.4 (PD1_AN), U16.4 (PD1_AN), U18.4 (-VO), U19.2 (V-), U19.3 (IN_+), U23.2, U24.4 (-VO), U25.2 (V-), U25.3 (IN_+), U28.2, U29.4 (PD1_AN), U30.4 (PD1_AN), U32.4 (-VO), U33.2 (V-), U33.3 (IN_+), U37.2, U38.4 (-VO), U39.2 (V-), U39.3 (IN_+), U42.2
unnamed: C6.1, C16.1, C26.1, C36.1, C46.1, C56.1, R1.2, R2.1, R8.2, R12.1, R21.2, R22.1, R28.2, R32.1, R41.2, R42.1, R48.2, R52.1
unnamed: D2.2 (A), D3.2 (A), D4.2 (A), D5.2 (A), D6.2 (A), D7.2 (A), R7.1, R17.1, R27.1, R37.1, R47.1, R57.1
unnamed: M2.4V1.2, M2.4V2.2, M2.4V3.2, M2.4V4.2, M2.4V5.2, M2.4V6.2, R4.1, R14.1, R24.1, R34.1, R44.1, R54.1
unnamed: M3.3V1.2, M3.3V2.2, M3.3V3.2, M3.3V4.2, M3.3V5.2, M3.3V6.2, R5.1, R15.1, R25.1, R35.1, R45.1, R55.1
unnamed: M5V1.2, M5V2.2, M5V3.2, M5V4.2, M5V5.2, M5V6.2, R6.1, R16.1, R26.1, R36.1, R46.1, R56.1
unnamed: R6.2, R9.1, R16.2, R18.1, R26.2, R29.1, R36.2, R38.1, R46.2, R49.1, R56.2, R58.1
unnamed: R3.2, R13.2, R23.2, R33.2, R43.2, R53.2, U1.1 (L_CAT), U2.1 (L_CAT), U15.1 (L_CAT), U16.1 (L_CAT), U29.1 (L_CAT), U30.1 (L_CAT)
unnamed: C2.2, C12.2, C22.2, C32.2, C42.2, C52.2, M2.4V1.1, M2.4V2.1, M2.4V3.1, M2.4V4.1, M2.4V5.1, M2.4V6.1, M3.3V1.1, M3.3V2.1, M3.3V3.1, M3.3V4.1, M3.3V5.1, M3.3V6.1, M5V1.1, M5V2.1, M5V3.1, M5V4.1, M5V5.1, M5V6.1, R11.1, R20.1, R31.1, R40.1, R51.1, R60.1, U3.1 (OUT), U6.1 (OUT), U17.1 (OUT), U20.1 (OUT), U31.1 (OUT), U34.1 (OUT)
unnamed: C3.1, C4.1, C13.1, C14.1, C23.1, C24.1, C33.1, C34.1, C43.1, C44.1, C53.1, C54.1, L1.2, L2.2, L3.2, L4.2, L5.2, L6.2, R7.2, R17.2, R27.2, R37.2, R47.2, R57.2, U4.1 (VIN), U10.1 (VIN), U18.1 (VIN), U24.1 (VIN), U32.1 (VIN), U38.1 (VIN)
unnamed: C7.2, C17.2, C27.2, C37.2, C47.2, C57.2, R3.1, R13.1, R23.1, R33.1, R43.1, R53.1, U5.1 (OUT), U11.1 (OUT), U19.1 (OUT), U25.1 (OUT), U33.1 (OUT), U39.1 (OUT)
unnamed: R10.1, R19.1, R30.1, R39.1, R50.1, R59.1, U7.1 (G), U12.1 (G), U21.1 (G), U26.1 (G), U35.1 (G), U40.1 (G)

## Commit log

2026-07-15 update: 2026-07-15 22:07:40
    [06_BOM_and_Calculations_RevB2_LCSC.xlsx, AnalogIsolator.kicad_pcb, AnalogIsolator.kicad_sch]
2026-07-17 update: fix schematic
    [AnalogIsolator.kicad_sch]
2026-07-18 update: fix design pcb
    [AnalogIsolator.kicad_pcb, AnalogIsolator.kicad_sch]
2026-07-18 update : add gerber file prodcution
    [AnalogIsolatorproduction-B_Cu.gbr, AnalogIsolatorproduction-B_Mask.gbr, AnalogIsolatorproduction-B_Paste.gbr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]
2026-07-18 docs: add visual PCB pinout guide
2026-07-18 docs: add shareable PCB pinout infographic
2026-07-18 docs: refresh product landing page
2026-07-18 update : update schematic
2026-07-18 docs: add BOM for latest schematic
    [09_BOM_Latest_Schematic_LCSC_Mouser.csv, 09_BOM_Latest_Schematic_LCSC_Mouser.xlsx]
2026-07-19 docs: clarify ESP32 default and sensor power limit
2026-07-19 docs: add external power protection guidance
2026-07-19 chore: sync latest KiCad and Rev B2 assets
    [AnalogIsolator.kicad_pcb, AnalogIsolator.kicad_sch, AnalogIsolatorproduction.kicad_pcb]
2026-07-19 chore: update KiCad history reference
